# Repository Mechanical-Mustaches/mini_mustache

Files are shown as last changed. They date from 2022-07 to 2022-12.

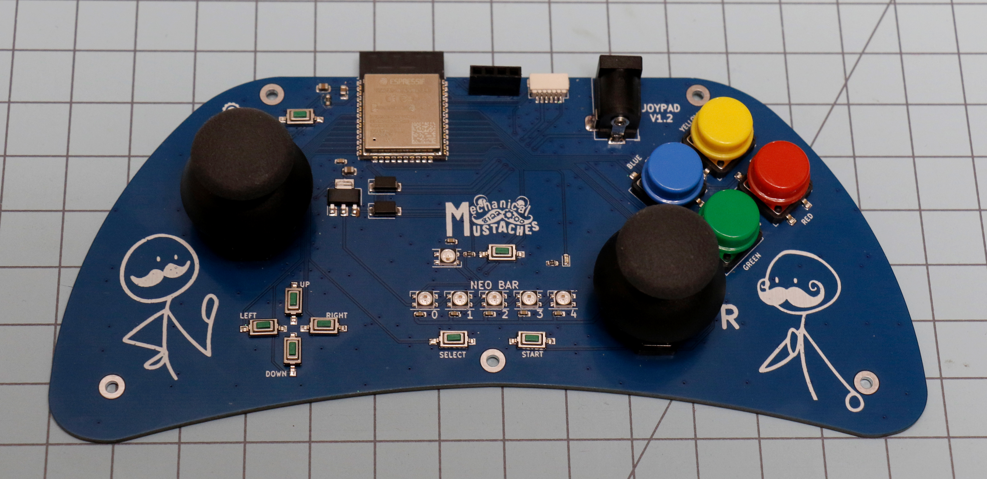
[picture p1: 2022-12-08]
press_kit/Jerry the Joypad.jpg

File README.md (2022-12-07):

Temporary home for a browser based serial terminal can be found here https://anfroholic.github.io/stache-terminal/

# Mo is live on Kickstarter!
Find more here https://www.kickstarter.com/projects/1474681136/mo-the-most-magnificent-mustached-machine 

_VZR4113

We are the Mechanical Mustaches
FIRST® Robotics Team 8122

mechanical mustaches 2022

this is Mo the mini_mustache robotic car

Mo Dance for the FIRST Time!

Mo Dances for the FIRST Time (https://www.youtube.com/watch?v=EEu2N_OLOB4)

Mo designed by our very own Olivia
mo_front
mo_back

Coming soon! Carl the Controller

carl_front
carl_back

here is a race put on by our amazing lead progammer Angie!!
Mo race_cover (https://www.youtube.com/watch?v=zQYqglGIxRU)

Still in development but some previews are:

Mo hosts webpages to edit himself
## Homepage
homepage

## Live coding REPL like code terminal
mos_repl

## Stachboard
Dashboard is autopopulated with motors, servos, agents and many other inputs and outputs that are created
stacheboard

## Mo also has an editor where you can edit your own code
editor

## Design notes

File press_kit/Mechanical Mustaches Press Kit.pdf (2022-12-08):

# Who we are

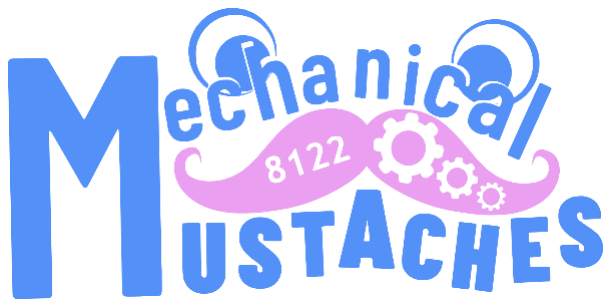
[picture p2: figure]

We are FIRST® Robotics Team 8122: The Mechanical Mustaches. We’re based out of William Howard Taft High School in Chicago, IL. FIRST is a youth-serving organization based around advancing STEM education. Every year there is a new challenge, and we build a 100+lb robot designed to complete a variety of different tasks.

We currently have about 50 team members ranging from freshmen to seniors.

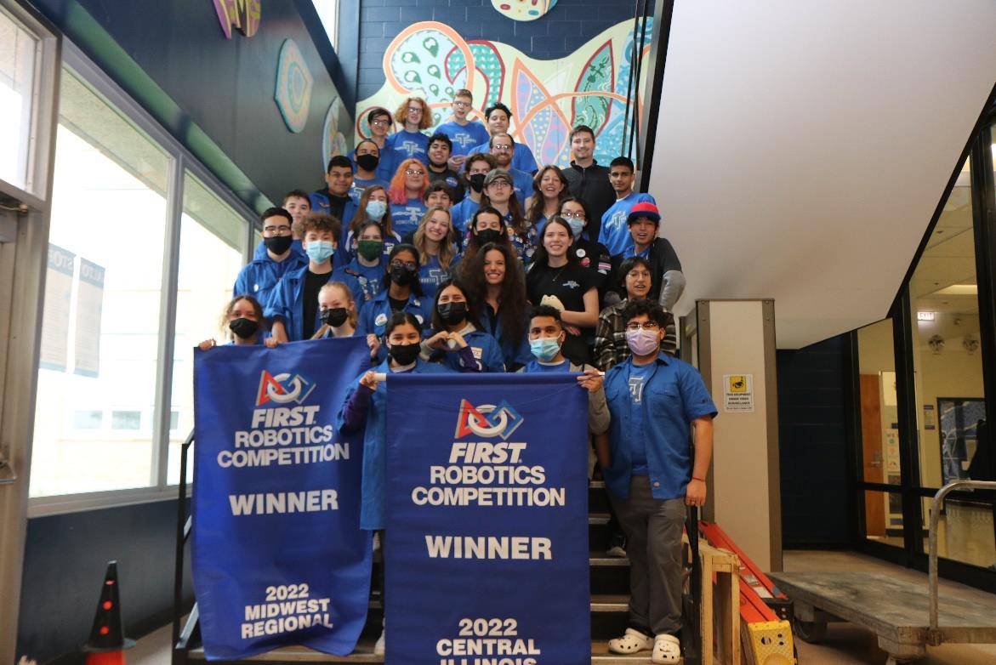
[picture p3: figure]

# Our Mission

Not everyone can grow a mustache, but everyone can grow as a mustache. We love to have fun! And the more mustache jokes the better!

We created Mo the robot to:

- To grow the use of the Python programming language in the FIRST® community
- To grow the FIRST® community by encouraging and empowering educators and coaches to start their own FIRST® Robotics teams
- To get robotics and FIRST® based curricula into the classroom

We also plan to use Mo in all these ways and the publicity generated by this campaign in a bid for our team to win the FIRST Impact Award and get our name in the FIRST Hall of Fame (https://www.firsthalloffame.org/)

# Mo the Robot

Where did Mo come from?

Mo started as a project between me, Andrew Wingate: Mentor of FIRST Robotics team 8122, The Mechanical Mustaches; and a few students to learn electrical engineering, programming and design. We didn't really have any goals other than to have fun when we started but hoped we could use this project to serve our team in the future. The large robots are expensive and access is limited. Additionally with the large robots failing is much more frowned upon. Learning should be fun and there should be no fear of getting things wrong (especially when it comes to programming)

We did have a lot of fun and the result was Mo! We shared Mo with our own students and with other teams, teachers and educators. They liked Mo too! That's when we started development on Jerry the joypad. With a controller and a robot, this really would be the same as programming the real large robots.

So we decided to try and get Mo into as many teams and schools as we could. We have talked with teams, and teachers. We have even talked with Chicago Public School's officials about getting Mo into real school curricula. Talks have been good and we’re looking forward to what’s coming.

We designed Mo to be easy to get started

- Mo serves his own webpages
- Mo has an easy-to-use autonomous mode
- Mo is programmed in python making learning easy
- Mo has a framework to help make complex systems easy
- Mo has many easy-to-use libraries already built in
- Mo already has many learning examples with more on the way

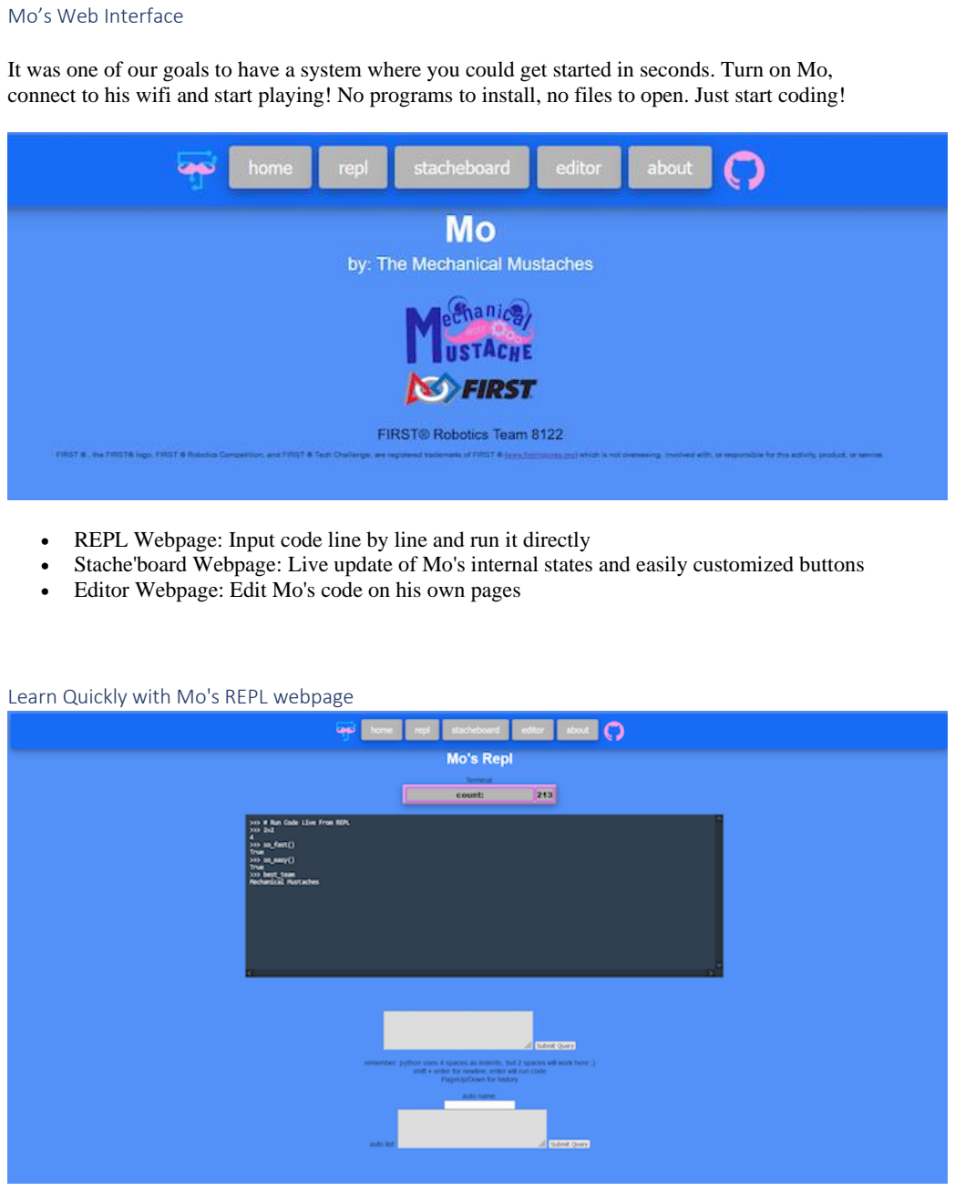
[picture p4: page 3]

Mo’s Web Interface

It was one of our goals to have a system where you could get started in seconds. Turn on Mo, connect to his wifi and start playing! No programs to install, no files to open. Just start coding!

- REPL Webpage: Input code line by line and run it directly
- Stache'board Webpage: Live update of Mo's internal states and easily customized buttons
- Editor Webpage: Edit Mo's code on his own pages

Learn Quickly with Mo's REPL webpage

- With Mo's repl you can input code directly. See immediately what your code does. If there is a mistake, Mo will tell you.
- Build confidence one line at a time.

See our repl practice on our wiki page here: (https://github.com/Mechanical-Mustaches/mini_mustache/wiki/REPL-Practice)

See live updates with Mo's Stache'board (dashboard) webpage

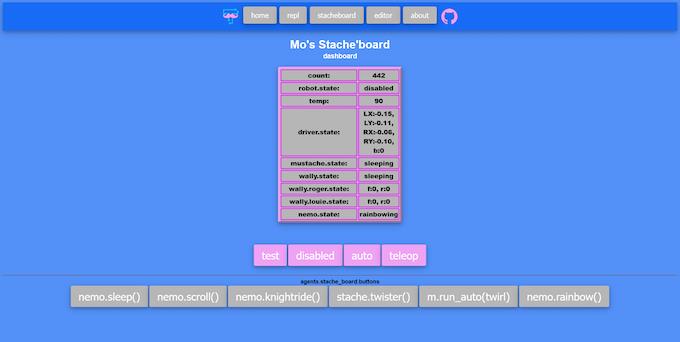
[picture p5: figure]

- With Mo's Agent based architecture important information is auto populated on Mo's Dashboard
- Easily create new buttons with custom functions
- Change Mo's states just like a real FIRST® Robotics competition robot!

Mo's Autonomous Modes

Mo comes built in with easy to use and easy to understand auto modes.

Notes from Andrew: My first career was in Tool & Die where I learned to write and use G-Code (a low level language used to drive CNC machining machines.) It was natural for me to look at lines of code and understand that the machine's would run one line of code at a time, and once that line had finished, it would move on to the next. I was amazed to find there was no comparable way to run code this way in programming languages like Python or anywhere else. So in our first season together Angie and I wrote Archie (later to be renamed mm.Auto)

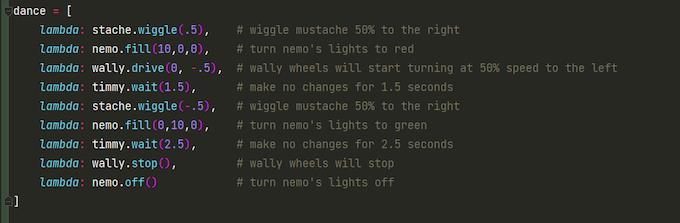
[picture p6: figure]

Mary had a little lambda

- Each line is executed one at a time in a very easy to understand fashion.
- Function calls are written the exact same way as you'd type it in code or in repl
- In 'auto' mode Auto will run all commands until it reaches a command like timmy.wait()
- Other wait like functions can be wait_for_a_button_press, or wait_until_an_encoder_reaches_position, or wait_for_counts and more
- We know what putting lambda before every function looks a little weird but it's how mm.Auto works.

You don't even need to put in all the lambdas

- In Mo's repl page is an Auto Maker that will automatically format a list and populate with all the lambdas

See more in depth explanations on Mo's wiki page (https://github.com/Mechanical-Mustaches/mini_mustache/wiki/Auto)

# Real FIRST® Robotics Robots Have Controllers

So we made Jerry the Joypad.

Jerry the Joypad is a controller you can use to remotely control Mo

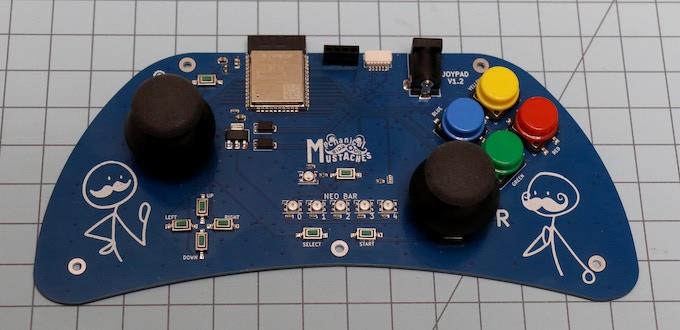
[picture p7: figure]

Jerry the Joypad Controller Board

Control Mo remotely with his friend Jerry the Joypad! Learn the interactions between a robot and a controller that is exactly the same as the interactions between controllers and FIRST® Robotics Competition Robots! Jerry and Mo talk to each other over wifi and is easy to set up

# The Most-Dashing Framework

When you learn how to program a Mo bot you already know how to program the large robots for the FIRST® Robotics competitions.

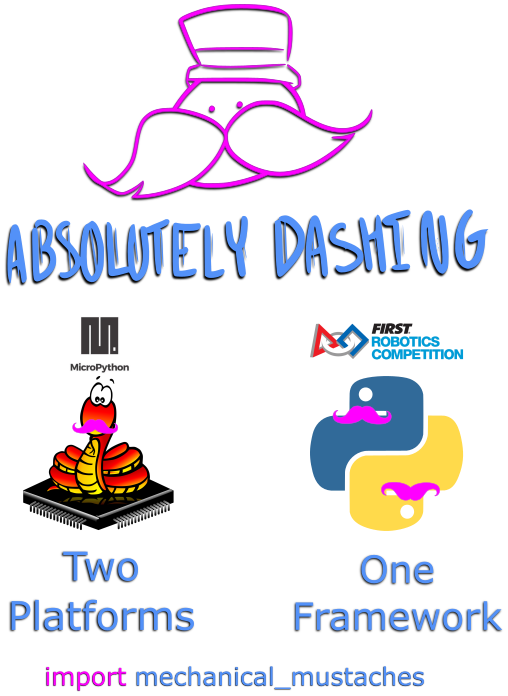
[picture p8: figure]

- Mo's framework and the Most-Dashing Framework were made at the same time
- Most code used with Mo can be directly used in FIRST®'s competition platforms

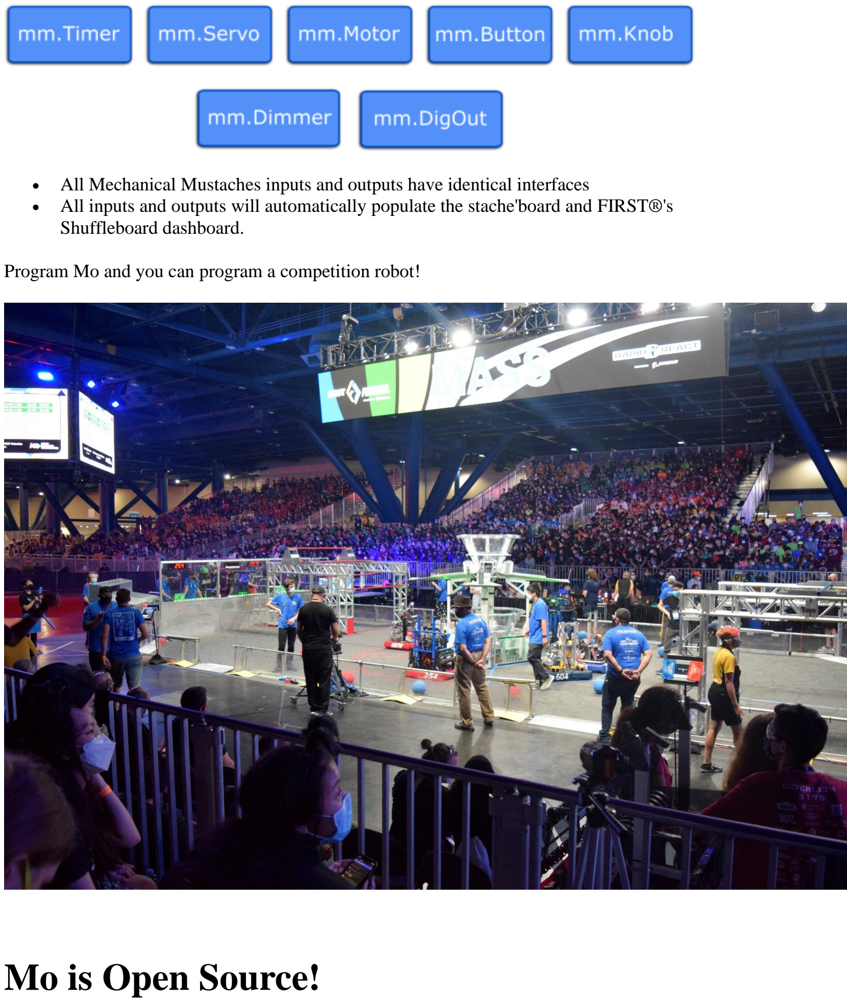
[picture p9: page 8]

- All Mechanical Mustaches inputs and outputs have identical interfaces
- All inputs and outputs will automatically populate the stache'board and FIRST®'s Shuffleboard dashboard.

Program Mo and you can program a competition robot!

# Mo is Open Source!

See our design files and code on the Mechanical Mustaches' Github pages

Mo and Jerry practice code and tutorials

- Mo's design files (https://github.com/Mechanical-Mustaches/mini_mustache/tree/main/cad-source-files/robo_car)
- Jerry's design files (https://github.com/Mechanical-Mustaches/mini_mustache/tree/main/cad-source-files/joypad)
- Mo's source code (https://github.com/Mechanical-Mustaches/mini_mustache/tree/main/code/src)
- Jerry's source code (https://github.com/Mechanical-Mustaches/mini_mustache/tree/main/code/joypad)
- Mo's expansion boards source files (https://github.com/Mechanical-Mustaches/mini_mustache/tree/main/cad-source-files/accessory-boards)

# Meet Our Build / Design Team

Meet our Lead Programmer, Angelina Bill

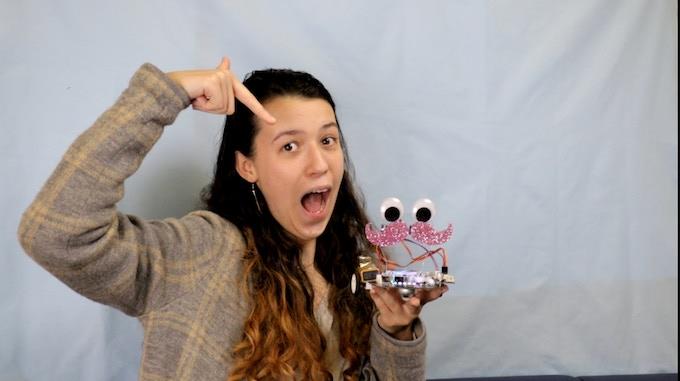
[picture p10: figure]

Meet all around Designer, Editor, Programmer and More, Yehansa Dissanayake

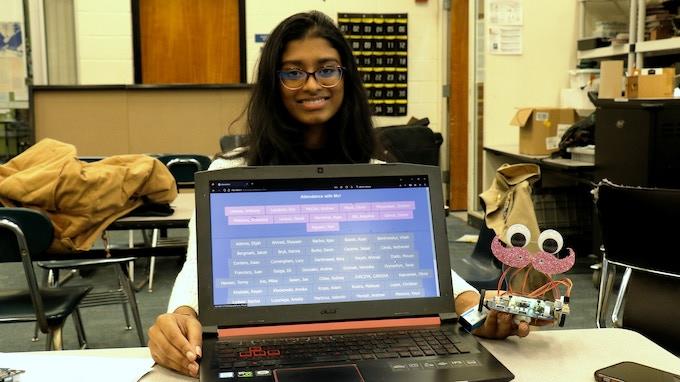
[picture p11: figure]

Yehansa used a Mo bot to take attendance for all our meetings. Mo serves an easy to use webpage where students only have to click on their name, at which point that name turns pink and moves to the top. At the same time Mo records the time and then Yehansa wrote a program that parses all the data Mo creates in an easy to parse format!

Meet our Electrical Engineer, Olivia

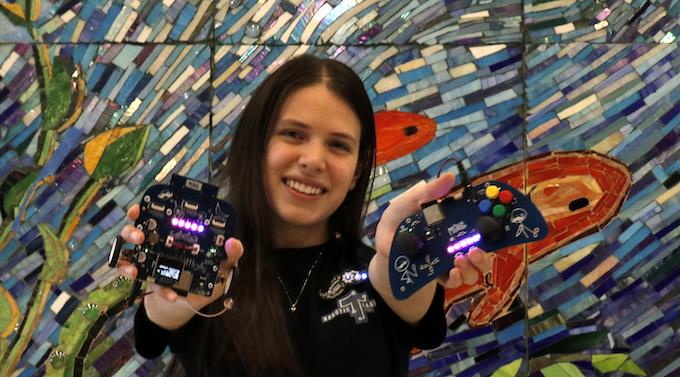
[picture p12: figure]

Olivia Kapusniak, Our Electrical Engineer

# The Story, Andrew's perspective:

Where did this project come from? The previous season, we started with a blinking cursor and had java as our language. I am a Python programmer but didn’t feel we had the time to transition the team to a new language, so we stayed with java. The next season Angie and I decided to not only move to Python (for obvious reasons) and create a framework to make development easier, faster and more fun! (not to mention a whole bunch of cool stuff.) Around the same time Olivia had stated her desire to major in college for computer engineering. We already completed a small circuit board project and I asked if she wanted to create a learning platform for our team. I was already using MicroPython in other projects so knew how we could mask the differences between the two platforms to create a smooth transition from little bots up to the big ones.

A few months later we knew a little about what we created and decided to create this campaign as a part of our bid for the FIRST® Robotics Impact Award. (https://www.firstinspires.org/resource-library/frc/first-impact-award-resources) Having been a part of a few teams now, I can say without a doubt that programming is the greatest hurdle both new and established teams face every year. The FIRST® community is wonderful. On a couple occasions we had other team’s programmers going around and helping teams polish their code on competition days. I wondered how many teams just don’t get started because the teacher or coach just didn’t think they had what it took to make a complete robot. If there was a way to cheaply prove that they were capable of creating a working program how many more teams could there be? At this point we had a few robots completed and were beginning to transition into the classroom environment. It was a goal that these robots would be able to be programmed on the hardware offered in the classrooms and more specifically CPS. (https://www.cps.edu/) In this case it was chromebooks. Not only could you not install programs on these devices, but you couldn’t even stick a thumb drive into them. (This is not because they are not capable of this, but more because of decisions made by CPS as an organization.)

So Mo got browser support. Luckily the microcontroller we were already using supported wifi and we began web development. This is where I finally started to believe that we actually had something. These little Mo bots start were a really good tool. (see campaign page for more) Not only was I able to teach a few kids to code, such as my nieces and nephews, but Angie herself was able to teach a classroom full of kids to program. Not only to program but create fun games like races and more. If a high school student could teach a bunch of kids, I have real hopes that we could make an impact and move a majority of FIRST® Robotics Teams over to a language more used in industry like Python than a language being used less and less like java. It’s my belief that it’s a necessity that our next generations have the ability to leverage robotic technologies. They must be orders of magnitude more productive than generations of the past. No longer will having a job of taking a doughnut from a conveyor and putting it in a box be a viable choice. We not only have to do all the work we’ve been doing, we also need to do all the work that we wish to have, so everyone can raise their standard of living. On top of all that we need to undo much of the poor work that has been done in the past, so we may restore and create a better world. I believe it’s in this generation to complete these tasks and more!

I would like to close with as much praise as I can muster to the three wonderful ladies that took charge of this project. Angie, Yehansa and Olivia have done a fantastic job and I couldn’t be prouder, not only for the work completed, but for their tenacity and willingness to stand up. I don’t really like phrases like “Women in STEM,” but I do agree with the sentiment. What I really want to see is more women in positions of power. I am saying these words more for the women I’ve worked with, than the general population. I have heard from women who have felt well mentored, but overlooked when it finally came time to pass the reigns. As a mentor myself, that puts me in a difficult situation. I try at every possible occasion to relieve myself from the decision making process, so they may flex those muscles and understand how it feels. Then use those muscles when it matters and have the confidence to take charge.

Contacts

Webpage: https://taftrobotics8122.wixsite.com/mechanical-mustaches

Github: https://github.com/Mechanical-Mustaches

Youtube: https://www.youtube.com/channel/UCmcKjrg92jrgkpf-8tHtKkQ

Twitter: https://twitter.com/RoboticsTaft

Instagram: https://www.instagram.com/8122_taftrobotics/

Andrew Wingate

Mentor: Mechanical Mustaches

President: Evezor Inc.

andrew@evezor.com

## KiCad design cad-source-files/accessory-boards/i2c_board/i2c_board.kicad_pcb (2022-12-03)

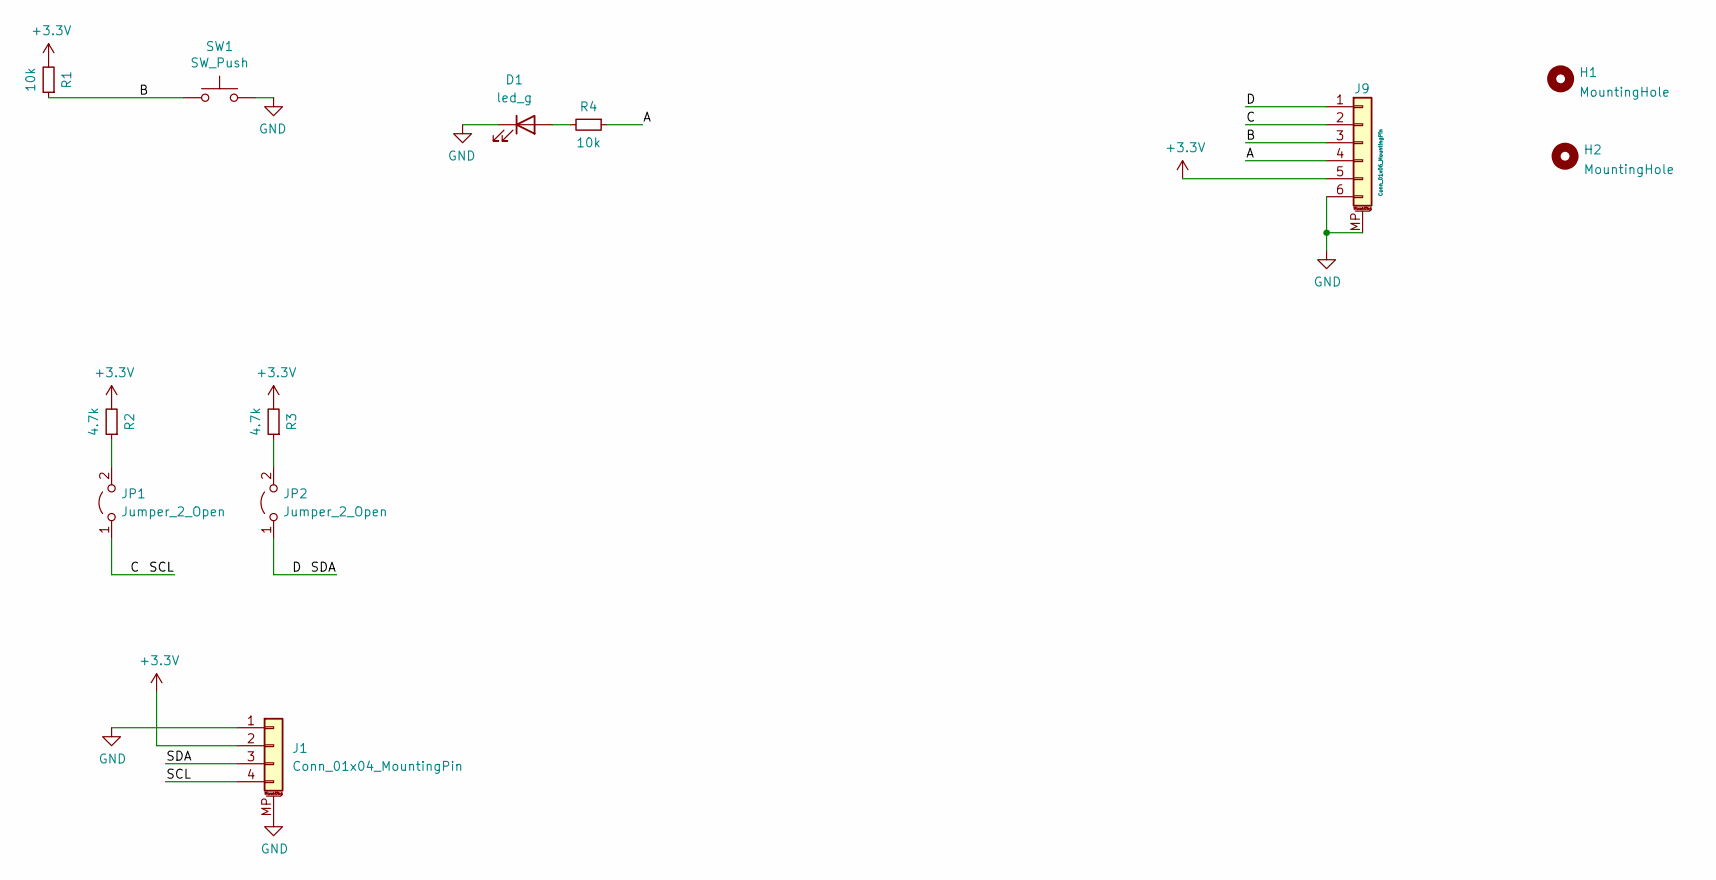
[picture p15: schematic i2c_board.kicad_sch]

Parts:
D1: led_g; LED_0603_1608Metric
H1, H2: MountingHole; MountingHole_3.2mm_M3_ISO14580
J1: Conn_01x04_MountingPin; JST_SH_SM04B-SRSS-TB_1x04-1MP_P1.00mm_Horizontal
J9: Conn_01x06_MountingPin; TE_84952-6_1x06-1MP_P1.0mm_Horizontal
JP1, JP2: Jumper_2_Open; SolderJumper-2_P1.3mm_Bridged_RoundedPad1.0x1.5mm
R1, R4: 10k; R_0603_1608Metric
R2, R3: 4.7k; R_0603_1608Metric
SW1: SW_Push; SWITCH_2x3_SMD_TACTILE_GREEN

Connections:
+3V3: J1.2, J9.5, R1.2, R2.2, R3.2
/A: J9.4, R4.1
/B: J9.3, R1.1, SW1.1
/C: J1.4, J9.2, JP1.1 (A)
/D: J1.3, J9.1, JP2.1 (A)
GND: D1.1 (K), J1.1, J1.MP (MountPin), J9.6, J9.MP (MountPin), SW1.2
unnamed: D1.2 (A), R4.2
unnamed: JP1.2 (B), R2.1
unnamed: JP2.2 (B), R3.1

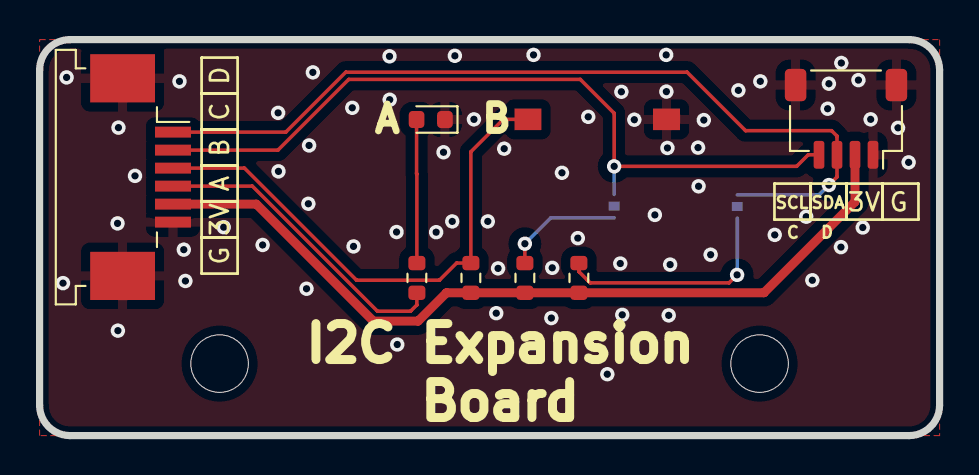
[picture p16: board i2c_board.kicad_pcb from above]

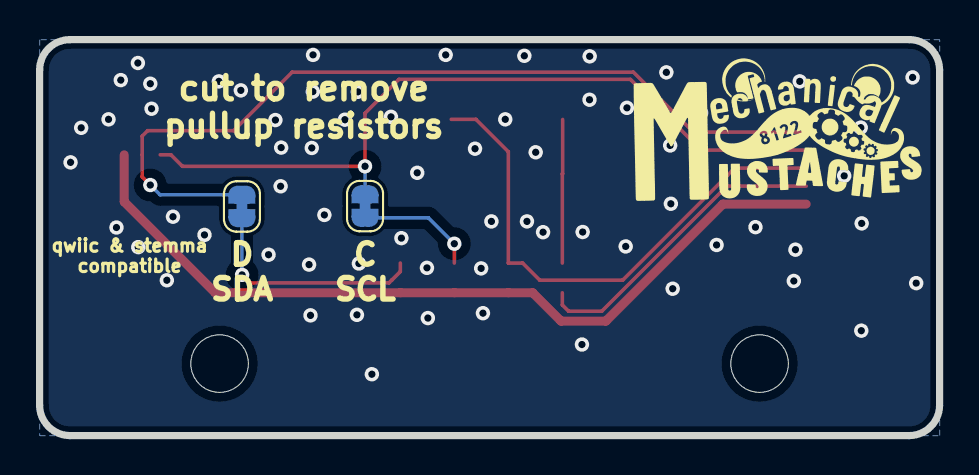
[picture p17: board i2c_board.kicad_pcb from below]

Board: 2 copper layers, 50.0 x 22.0 mm, 12 parts (2 on the bottom side), 9 nets.

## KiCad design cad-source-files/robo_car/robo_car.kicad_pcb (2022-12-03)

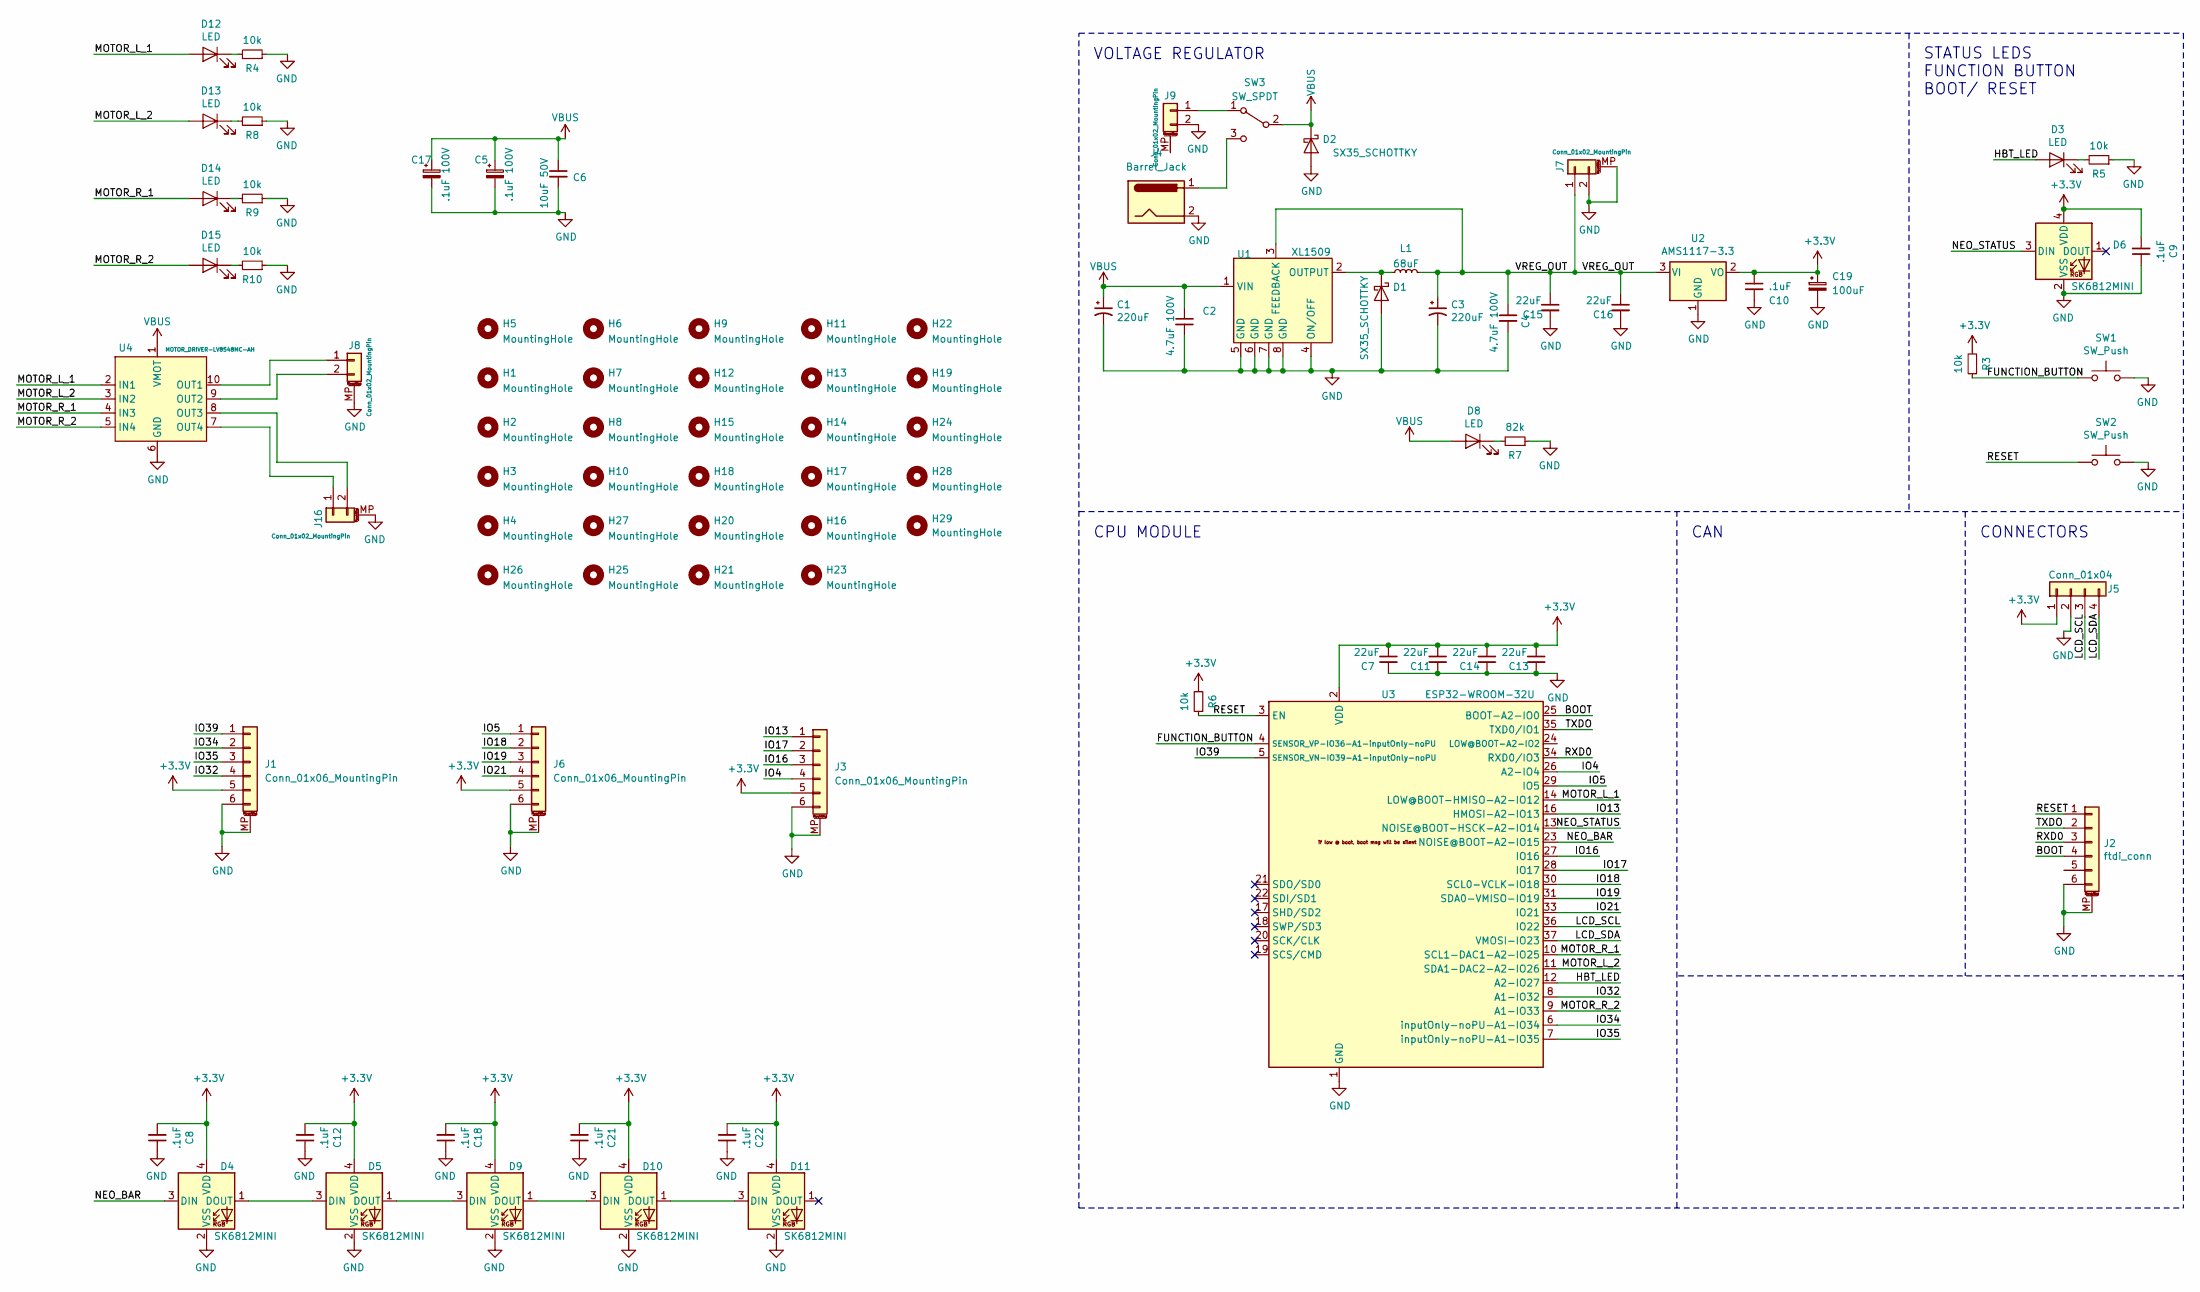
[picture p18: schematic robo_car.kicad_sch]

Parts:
C1, C3: 220uF; CP_Elec_10x10.5
C2, C4: 4.7uF 100V; C_0805_2012Metric
C5, C17: .1uF 100V; C_0805_2012Metric
C6: 10uF 50V; C_1206_3216Metric
C7, C11, C13, C14, C15, C16: 22uF; C_0805_2012Metric
C8, C9, C10, C12, C18, C21, C22: .1uF; C_0603_1608Metric
C19: 100uF; CP_EIA-3528-21_Kemet-B
D1, D2: SX35_SCHOTTKY; D_SMA
D3, D8, D12, D13, D14, D15: LED; LED_0603_1608Metric
D4, D5, D6, D9, D10, D11: SK6812MINI; LED_SK6812MINI_PLCC4_3.5x3.5mm_P1.75mm
H1, H2, H3, H4, H5, H6, H7, H8, H9, H10, H11, H12, H13, H14, H15, H16, H17, H18, H19, H20, H25, H26, H27, H28, H29: MountingHole; MountingHole_3.2mm_M3_ISO14580
H21, H22, H23, H24: MountingHole; MountingHole_2.7mm_M2.5_ISO14580
J1, J3, J6: Conn_01x06_MountingPin; TE_84952-6_1x06-1MP_P1.0mm_Horizontal
J2: ftdi_conn; JST_SH_SM06B-SRSS-TB_1x06-1MP_P1.00mm_Horizontal
J4: Barrel_Jack; BarrelJack_Horizontal
J5: Conn_01x04; PinSocket_1x04_P2.54mm_Vertical
J7: Conn_01x02_MountingPin; JST_PH_B2B-PH-K_1x02_P2.00mm_Vertical
J8, J16: Conn_01x02_MountingPin; JST_PH_S2B-PH-K_1x02_P2.00mm_Horizontal
J9: Conn_01x02_MountingPin; JST_XH_B2B-XH-AM_1x02_P2.50mm_Vertical
L1: 68uF; INDUCTOR-68uH
R3, R4, R5, R6, R8, R9, R10: 10k; R_0603_1608Metric
R7: 82k; R_0603_1608Metric
SW1, SW2: SW_Push; SWITCH_2x3_SMD_TACTILE_GREEN
SW3: SW_SPDT; SW_SLIDE_SS-12D10L9
U1: XL1509; SOIC-8_3.9x4.9mm_P1.27mm
U2: AMS1117-3.3; SOT-223-3_TabPin2
U3: ESP32-WROOM-32U; ESP32-WROOM-32U_evezor
U4: MOTOR_DRIVER-LV8548MC-AH; SOIC-10_LV8548MC-AH_evezor

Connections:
+3V3: C7.1, C8.2, C9.2, C10.1, C11.1, C12.2, C13.1, C14.1, C18.2, C19.1, C21.2, C22.2, D4.4 (VDD), D5.4 (VDD), D6.4 (VDD), D9.4 (VDD), D10.4 (VDD), D11.4 (VDD), J1.5, J3.5, J5.1, J6.5, R3.2, R6.2, U2.2 (VO), U3.2 (VDD); also elsewhere on the board
/BOOT: J2.4, U3.25 (BOOT-A2-IO0)
/FUNCTION_BUTTON: R3.1, SW1.1, U3.4 (SENSOR_VP-IO36-A1-inputOnly-noPU)
/HBT_LED: D3.2 (A), U3.12 (A2-IO27)
/IO4: J3.4, U3.26 (A2-IO4)
/IO5: J6.1, U3.29 (IO5)
/IO13: J3.1, U3.16 (HMOSI-A2-IO13)
/IO16: J3.3, U3.27 (IO16)
/IO17: J3.2, U3.28 (IO17)
/IO18: J6.2, U3.30 (SCL0-VCLK-IO18)
/IO19: J6.3, U3.31 (SDA0-VMISO-IO19)
/IO21: J6.4, U3.33 (IO21)
/IO32: J1.4, U3.8 (A1-IO32)
/IO34: J1.2, U3.6 (inputOnly-noPU-A1-IO34)
/IO35: J1.3, U3.7 (inputOnly-noPU-A1-IO35)
/IO39: J1.1, U3.5 (SENSOR_VN-IO39-A1-inputOnly-noPU)
/LCD_SCL: J5.3, U3.36 (IO22)
/LCD_SDA: J5.4, U3.37 (VMOSI-IO23)
/MOTOR_L_1: D12.2 (A), U3.14 (LOW@BOOT-HMISO-A2-IO12), U4.2 (IN1)
/MOTOR_L_2: D13.2 (A), U3.11 (SDA1-DAC2-A2-IO26), U4.3 (IN2)
/MOTOR_R_1: D14.2 (A), U3.10 (SCL1-DAC1-A2-IO25), U4.4 (IN3)
/MOTOR_R_2: D15.2 (A), U3.9 (A1-IO33), U4.5 (IN4)
/NEO_BAR: D4.3 (DIN), U3.23 (NOISE@BOOT-A2-IO15)
/NEO_STATUS: D6.3 (DIN), U3.13 (NOISE@BOOT-HSCK-A2-IO14)
/RESET: J2.1, R6.1, SW2.1, U3.3 (EN)
/RXD0: J2.3, U3.34 (RXD0/IO3)
/TXDO: J2.2, U3.35 (TXD0/IO1)
/VREG_OUT: C3.1, C4.1, C15.1, C16.1, J7.1, L1.1, U1.3 (FEEDBACK), U2.3 (VI)
GND: C1.2, C2.2, C3.2, C4.2, C5.2, C6.2, C7.2, C8.1, C9.1, C10.2, C11.2, C12.1, C13.2, C14.2, C15.2, C16.2, C17.2, C18.1, C19.2, C21.1, C22.1, D1.2 (A), D2.2 (A), D4.2 (VSS), D5.2 (VSS), D6.2 (VSS), D9.2 (VSS), D10.2 (VSS), D11.2 (VSS), J1.6, J1.MP (MountPin), J2.6, J2.MP (MountPin), J3.6, J3.MP (MountPin), J4.2, J5.2, J6.6, J6.MP (MountPin), J7.2, J7.MP (MountPin), J8.MP (MountPin), J9.2, J16.MP (MountPin), R4.1, R5.1, R7.1, R8.1, R9.1, R10.1, SW1.2, SW2.2, U1.4 (ON/OFF), U1.5 (GND), U1.6 (GND), U1.7 (GND), U1.8 (GND), U2.1 (GND), U3.1 (GND), U3.15 (GND), U3.38 (GND), U3.39 (GND), U4.6 (GND); also elsewhere on the board
unnamed: D1.1 (K), L1.2, U1.2 (OUTPUT)
unnamed: D3.1 (K), R5.2
unnamed: D4.1 (DOUT), D5.3 (DIN)
unnamed: D5.1 (DOUT), D9.3 (DIN)
unnamed: D8.1 (K), R7.2
unnamed: D10.1 (DOUT), D11.3 (DIN)
unnamed: D9.1 (DOUT), D10.3 (DIN)
unnamed: D12.1 (K), R4.2
unnamed: D13.1 (K), R8.2
unnamed: D14.1 (K), R9.2
unnamed: D15.1 (K), R10.2
unnamed: J4.1, SW3.3 (C)
unnamed: J8.1, U4.10 (OUT1)
unnamed: J8.2, U4.9 (OUT2)
unnamed: J9.1, SW3.1 (A)
unnamed: J16.1, U4.7 (OUT4)
unnamed: J16.2, U4.8 (OUT3)
VBUS: C1.1, C2.1, C5.1, C6.1, C17.1, D2.1 (K), D8.2 (A), SW3.2 (B), U1.1 (VIN), U4.1 (VMOT)

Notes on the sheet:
VOLTAGE REGULATOR
CPU MODULE
CAN
STATUS LEDS FUNCTION BUTTON BOOT/ RESET
CONNECTORS

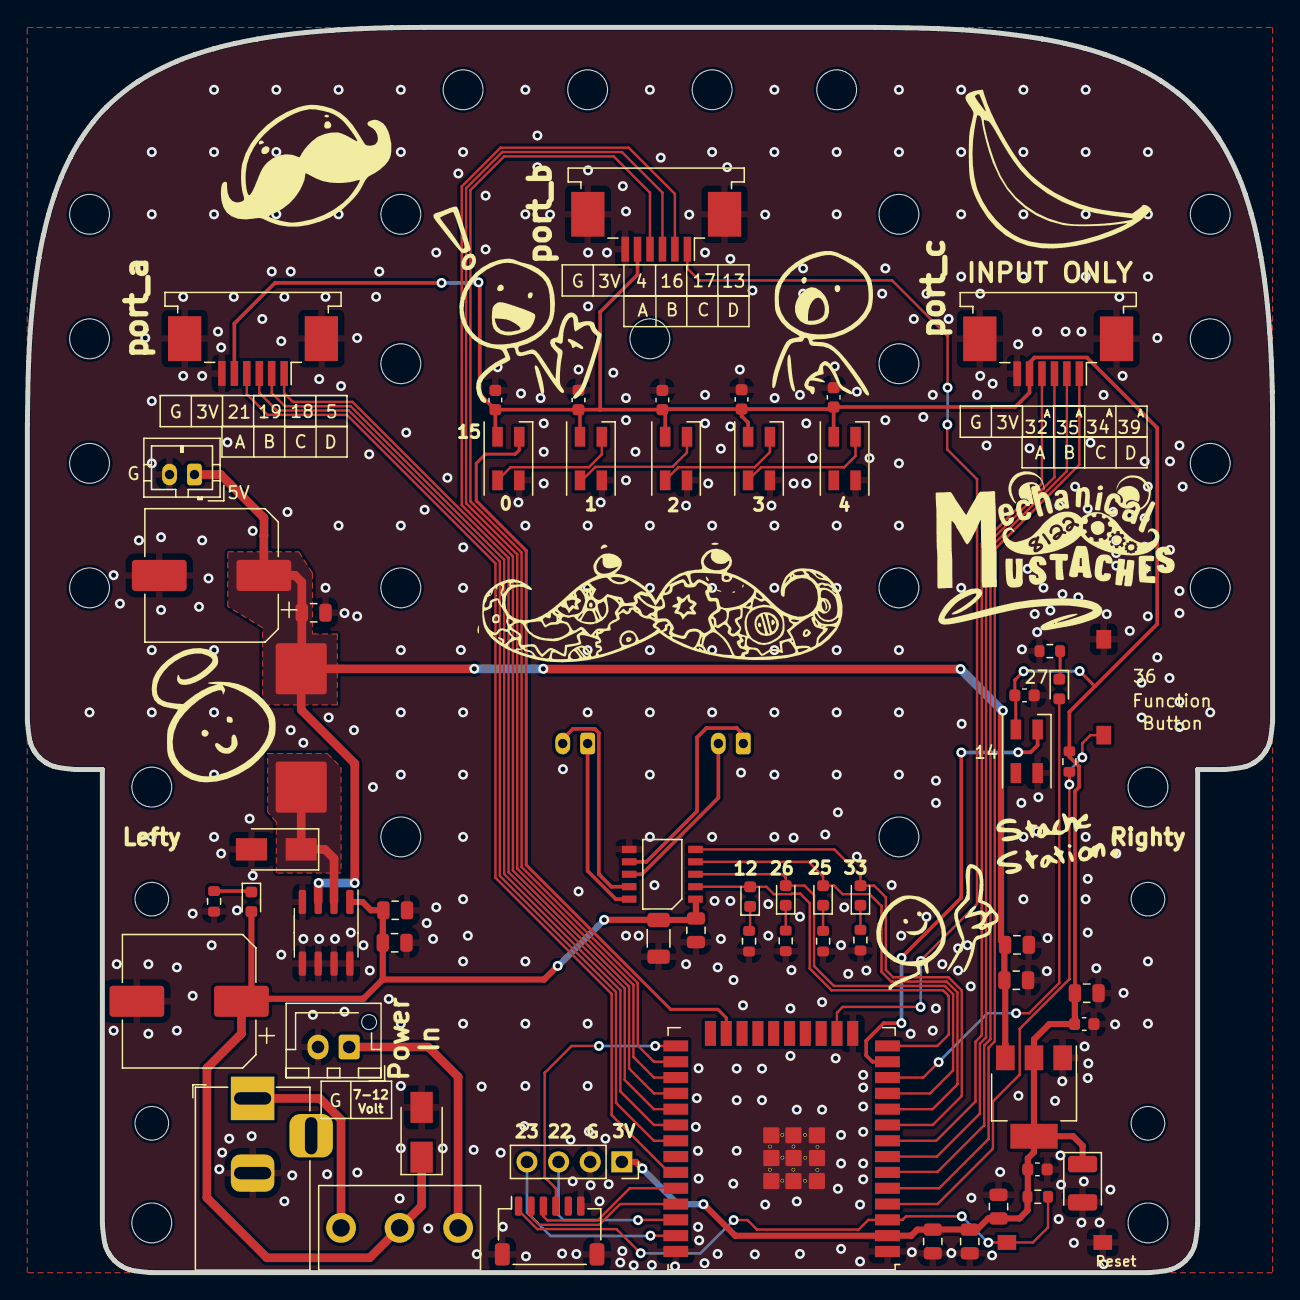
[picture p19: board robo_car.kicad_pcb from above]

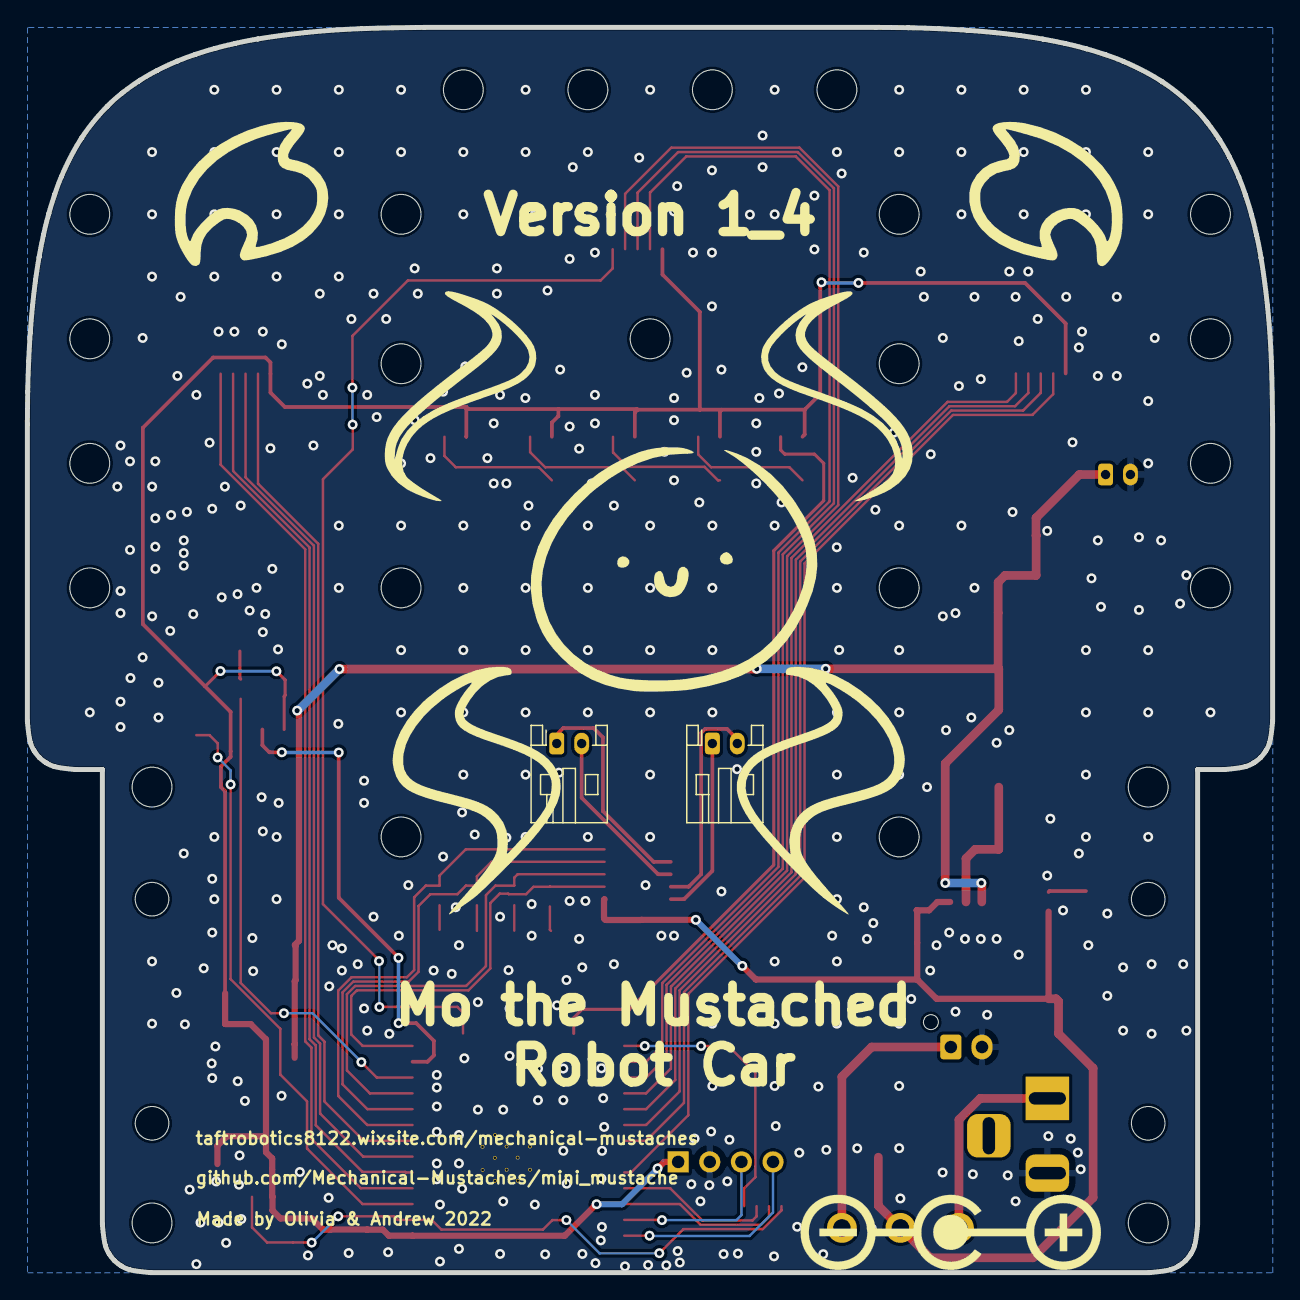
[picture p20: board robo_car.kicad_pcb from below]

Board: 2 copper layers, 100.0 x 100.0 mm, 91 parts (2 on the bottom side), 47 nets.

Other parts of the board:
C14#2: .1uF; C_0603_1608Metric

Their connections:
+3V3: C14#2.1; also elsewhere on the board
GND: C14#2.2; also elsewhere on the board

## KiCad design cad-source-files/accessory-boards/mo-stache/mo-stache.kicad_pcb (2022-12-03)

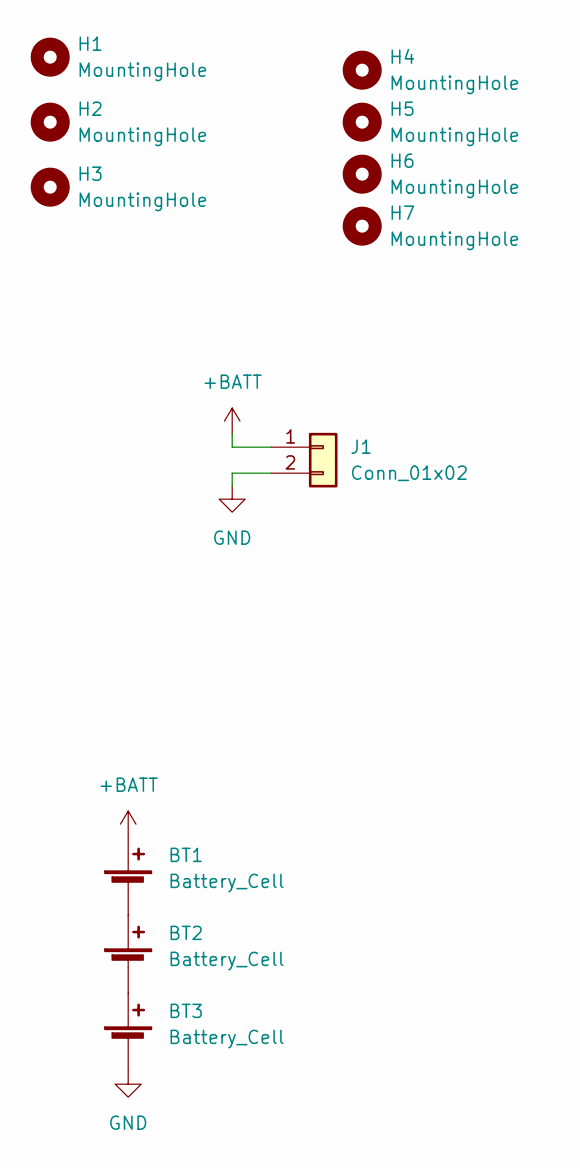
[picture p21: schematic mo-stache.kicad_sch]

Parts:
BT1, BT2, BT3: Battery_Cell; 16350_holder
H1, H2, H3: MountingHole; MountingHole_4.95mm_3_16in
H4, H5, H6, H7: MountingHole; MountingHole_2.7mm_M2.5_ISO7380
J1: Conn_01x02; JST_XH_B2B-XH-AM_1x02_P2.50mm_Vertical

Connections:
+BATT: BT1.1 (+), J1.1
GND: BT3.2 (-), J1.2
unnamed: BT1.2 (-), BT2.1 (+)
unnamed: BT2.2 (-), BT3.1 (+)

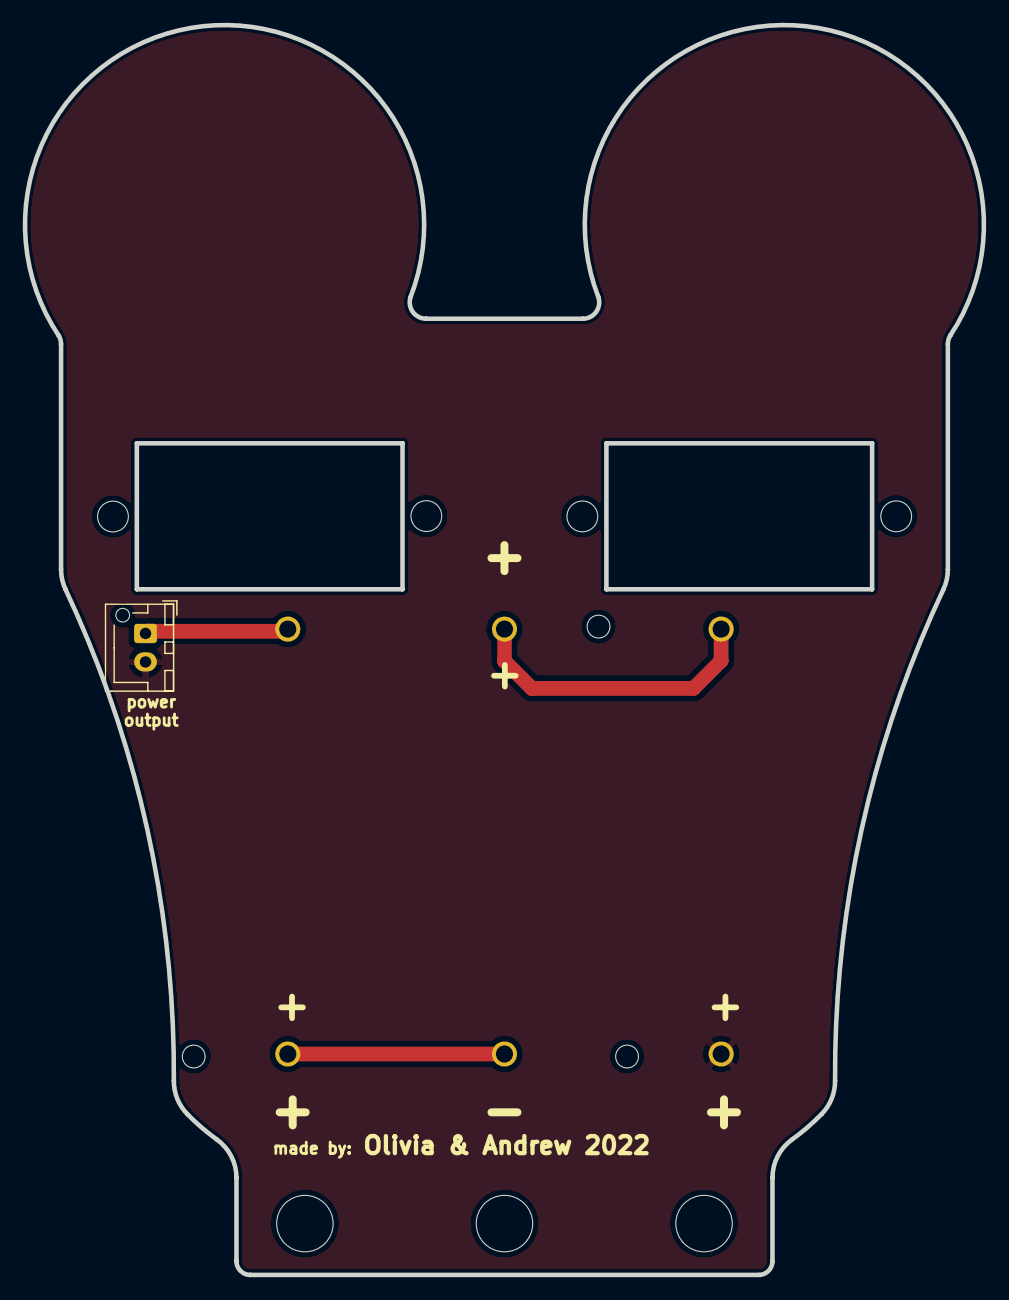
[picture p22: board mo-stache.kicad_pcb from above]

Board: 2 copper layers, 84.1 x 109.6 mm, 11 parts (0 on the bottom side), 4 nets.

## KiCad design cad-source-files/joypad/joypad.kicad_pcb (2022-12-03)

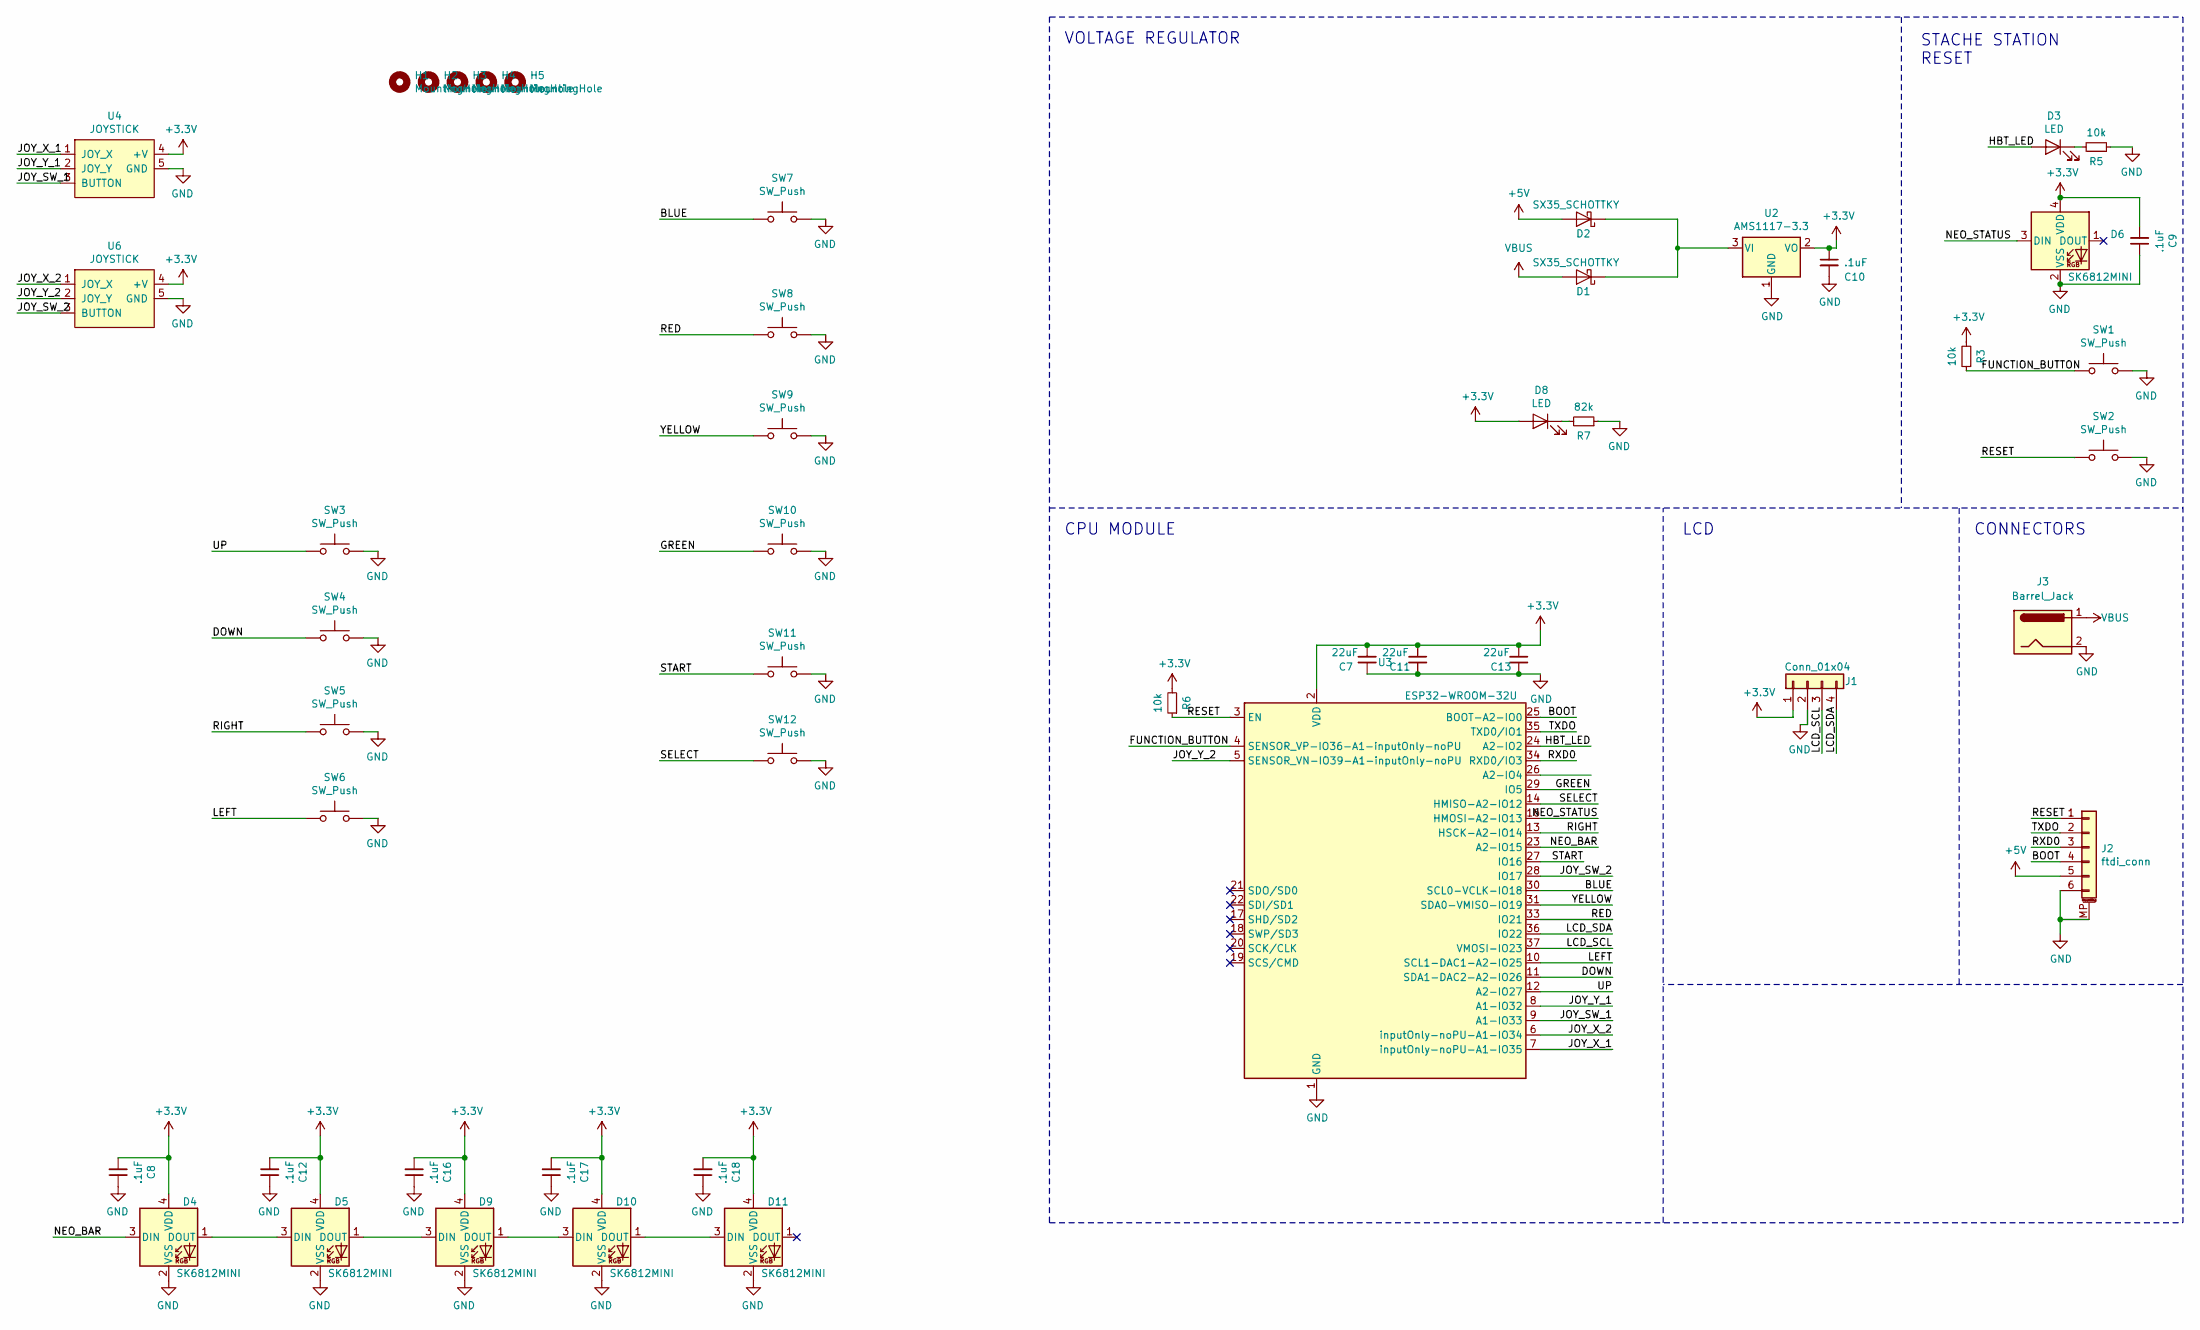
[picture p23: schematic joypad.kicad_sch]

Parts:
C7, C11, C13: 22uF; C_0805_2012Metric
C8, C9, C10, C12, C16, C17, C18: .1uF; C_0603_1608Metric
D1, D2: SX35_SCHOTTKY; D_SMA
D3, D8: LED; LED_0603_1608Metric
D4, D5, D6, D9, D10, D11: SK6812MINI; LED_SK6812MINI_PLCC4_3.5x3.5mm_P1.75mm
H1, H2, H3, H4, H5: MountingHole; MountingHole_2.5mm_Pad
J1: Conn_01x04; PinSocket_1x04_P2.54mm_Vertical
J2: ftdi_conn; JST_SH_SM06B-SRSS-TB_1x06-1MP_P1.00mm_Horizontal
J3: Barrel_Jack; BarrelJack_Horizontal
R3, R5, R6: 10k; R_0603_1608Metric
R7: 82k; R_0603_1608Metric
SW1, SW2, SW3, SW4, SW5, SW6, SW11, SW12: SW_Push; SWITCH_2x3_SMD_TACTILE_GREEN
SW7, SW8, SW9, SW10: SW_Push; 12mm_pushbutton
U2: AMS1117-3.3; SOT-223-3_TabPin2
U3: ESP32-WROOM-32U; ESP32-WROOM-32U_evezor
U4, U6: JOYSTICK

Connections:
+3V3: C7.1, C8.2, C9.2, C10.1, C11.1, C12.2, C13.1, C16.2, C17.2, C18.2, D4.4 (VDD), D5.4 (VDD), D6.4 (VDD), D8.2 (A), D9.4 (VDD), D10.4 (VDD), D11.4 (VDD), J1.1, R3.2, R6.2, U2.2 (VO), U3.2 (VDD), U4.4 (+V), U6.4 (+V)
+5V: D2.2 (A), J2.5
/BLUE: SW7.1, U3.30 (SCL0-VCLK-IO18)
/BOOT: J2.4, U3.25 (BOOT-A2-IO0)
/DOWN: SW4.1, U3.11 (SDA1-DAC2-A2-IO26)
/FUNCTION_BUTTON: R3.1, SW1.1, U3.4 (SENSOR_VP-IO36-A1-inputOnly-noPU)
/GREEN: SW10.1, U3.29 (IO5)
/HBT_LED: D3.2 (A), U3.24 (A2-IO2)
/JOY_SW_1: U3.9 (A1-IO33), U4.3 (BUTTON)
/JOY_SW_2: U3.28 (IO17), U6.3 (BUTTON)
/JOY_X_1: U3.7 (inputOnly-noPU-A1-IO35), U4.1 (JOY_X)
/JOY_X_2: U3.6 (inputOnly-noPU-A1-IO34), U6.1 (JOY_X)
/JOY_Y_1: U3.8 (A1-IO32), U4.2 (JOY_Y)
/JOY_Y_2: U3.5 (SENSOR_VN-IO39-A1-inputOnly-noPU), U6.2 (JOY_Y)
/LCD_SCL: J1.3, U3.37 (VMOSI-IO23)
/LCD_SDA: J1.4, U3.36 (IO22)
/LEFT: SW6.1, U3.10 (SCL1-DAC1-A2-IO25)
/NEO_BAR: D4.3 (DIN), U3.23 (A2-IO15)
/NEO_STATUS: D6.3 (DIN), U3.16 (HMOSI-A2-IO13)
/RED: SW8.1, U3.33 (IO21)
/RESET: J2.1, R6.1, SW2.1, U3.3 (EN)
/RIGHT: SW5.1, U3.13 (HSCK-A2-IO14)
/RXD0: J2.3, U3.34 (RXD0/IO3)
/SELECT: SW12.1, U3.14 (HMISO-A2-IO12)
/START: SW11.1, U3.27 (IO16)
/TXDO: J2.2, U3.35 (TXD0/IO1)
/UP: SW3.1, U3.12 (A2-IO27)
/YELLOW: SW9.1, U3.31 (SDA0-VMISO-IO19)
GND: C7.2, C8.1, C9.1, C10.2, C11.2, C12.1, C13.2, C16.1, C17.1, C18.1, D4.2 (VSS), D5.2 (VSS), D6.2 (VSS), D9.2 (VSS), D10.2 (VSS), D11.2 (VSS), J1.2, J2.6, J2.MP (MountPin), J3.2, R5.1, R7.1, SW1.2, SW2.2, SW3.2, SW4.2, SW5.2, SW6.2, SW7.2, SW8.2, SW9.2, SW10.2, SW11.2, SW12.2, U2.1 (GND), U3.1 (GND), U3.15 (GND), U3.38 (GND), U3.39 (GND), U4.5 (GND), U6.5 (GND)
unnamed: D1.1 (K), D2.1 (K), U2.3 (VI)
unnamed: D3.1 (K), R5.2
unnamed: D4.1 (DOUT), D5.3 (DIN)
unnamed: D5.1 (DOUT), D9.3 (DIN)
unnamed: D8.1 (K), R7.2
unnamed: D10.1 (DOUT), D11.3 (DIN)
unnamed: D9.1 (DOUT), D10.3 (DIN)
VBUS: D1.2 (A), J3.1

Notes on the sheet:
VOLTAGE REGULATOR
CPU MODULE
LCD
STACHE STATION RESET
CONNECTORS

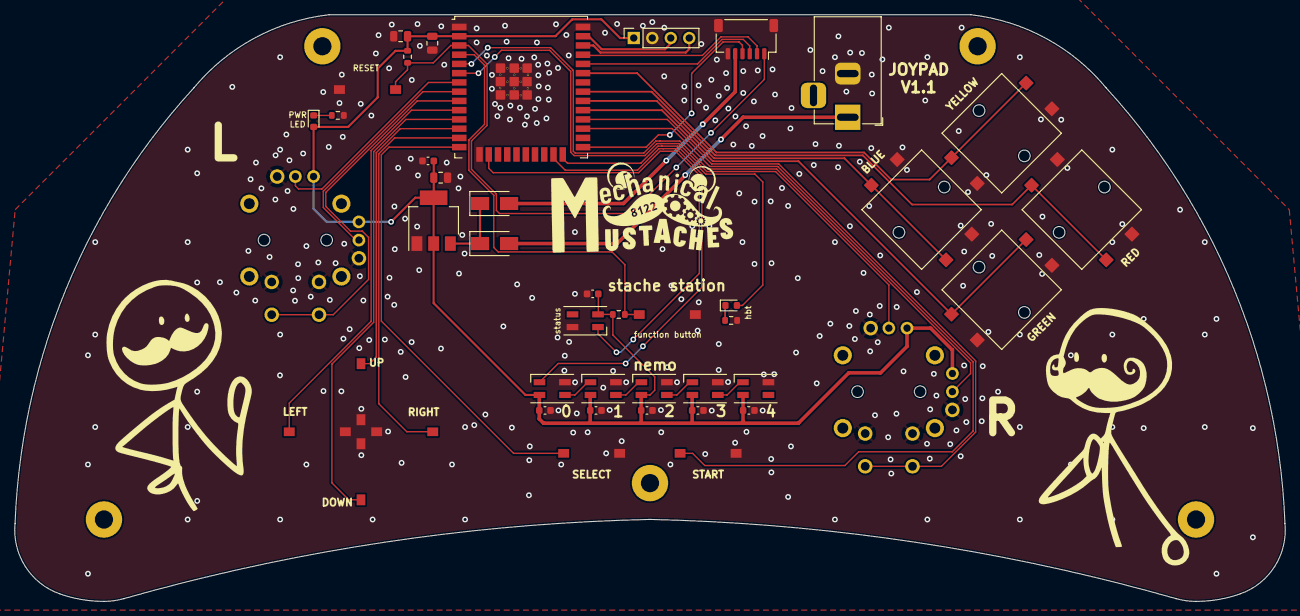
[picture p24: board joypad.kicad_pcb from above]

Board: 2 copper layers, 174.5 x 80.6 mm, 48 parts (0 on the bottom side), 37 nets.

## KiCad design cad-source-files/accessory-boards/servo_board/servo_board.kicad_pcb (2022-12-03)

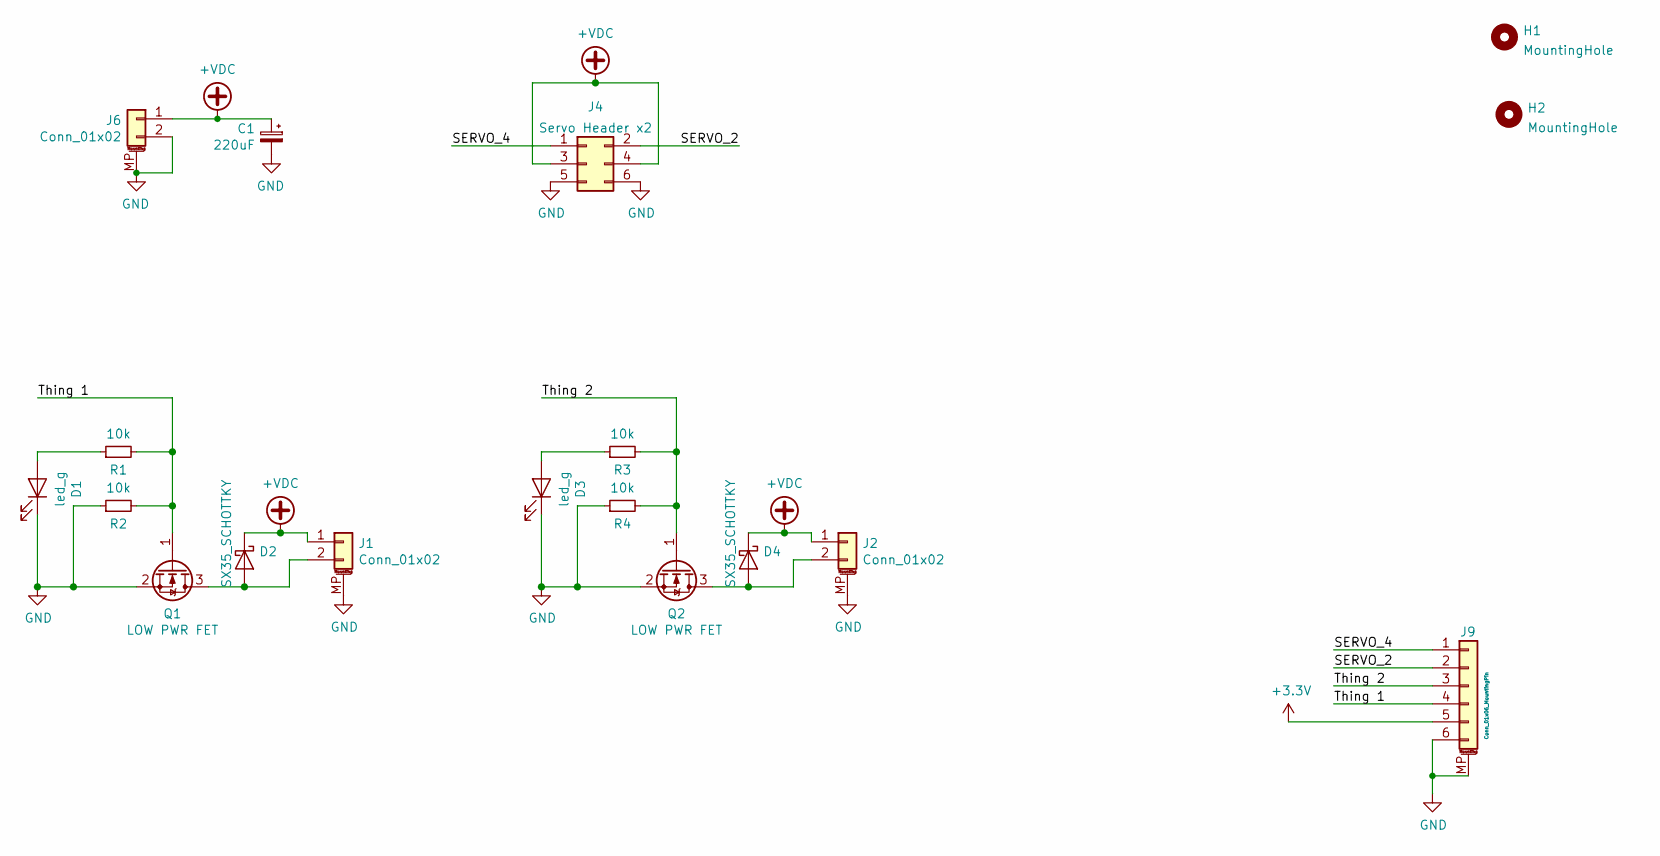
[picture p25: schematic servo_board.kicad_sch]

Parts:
C1: 220uF; CP_Elec_8x6.5
D1, D3: led_g; LED_0603_1608Metric
D2, D4: SX35_SCHOTTKY; D_SMA
H1, H2: MountingHole; MountingHole_3.2mm_M3_ISO14580
J1, J2: Conn_01x02; JST_XH_2_VERTICAL
J4: Servo Header x2; PinHeader_2x03_P2.54mm_Vertical_SMD
J6: Conn_01x02; JST_PH_B2B-PH-SM4-TB_1x02-1MP_P2.00mm_Vertical
J9: Conn_01x06_MountingPin; TE_84952-6_1x06-1MP_P1.0mm_Horizontal
Q1, Q2: LOW PWR FET; SOT-23
R1, R2, R3, R4: 10k; R_0603_1608Metric

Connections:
+3V3: J9.5
+VDC: C1.1, D2.1 (K), D4.1 (K), J1.1, J2.1, J4.3, J4.4, J6.1
/SERVO_2: J4.2, J9.2
/SERVO_4: J4.1, J9.1
/Thing 1: J9.4, Q1.1 (G), R1.2, R2.2
/Thing 2: J9.3, Q2.1 (G), R3.2, R4.2
GND: C1.2, D1.1 (K), D3.1 (K), J1.MP (MountPin), J2.MP (MountPin), J4.5, J4.6, J6.2, J6.MP (MountPin), J9.6, J9.MP (MountPin), Q1.2 (S), Q2.2 (S), R2.1, R4.1
unnamed: D1.2 (A), R1.1
unnamed: D2.2 (A), J1.2, Q1.3 (D)
unnamed: D3.2 (A), R3.1
unnamed: D4.2 (A), J2.2, Q2.3 (D)

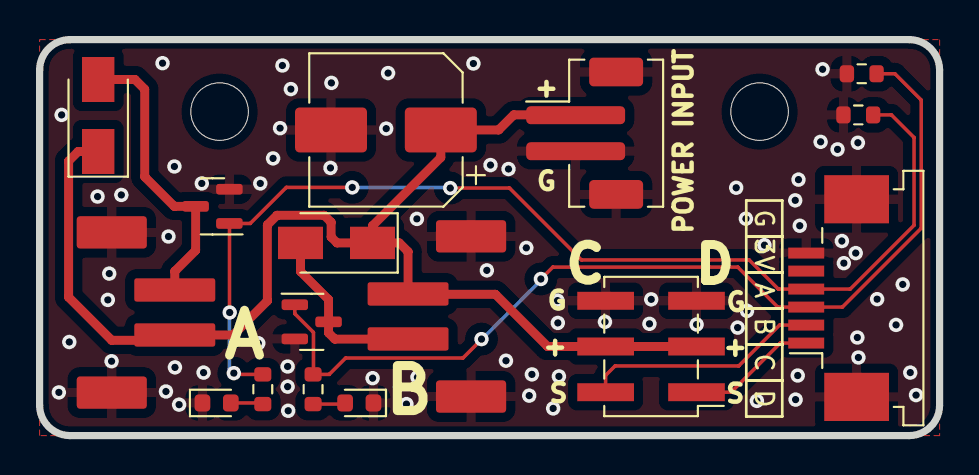
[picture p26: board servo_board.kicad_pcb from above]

Board: 2 copper layers, 50.0 x 22.0 mm, 18 parts (0 on the bottom side), 10 nets.

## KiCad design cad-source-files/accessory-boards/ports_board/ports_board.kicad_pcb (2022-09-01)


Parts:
H1, H2: MountingHole; MountingHole_3.2mm_M3_ISO14580
J2, J5, J7, J8: Conn_01x03; JST_PH_B3B-PH-SM4-TB_1x03-1MP_P2.00mm_Vertical
J9: Conn_01x06_MountingPin; TE_84952-6_1x06-1MP_P1.0mm_Horizontal

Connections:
+3V3: J2.2, J5.2, J7.2, J8.2, J9.5
/A: J2.1, J9.1
/B: J5.1, J9.2
/C: J7.1, J9.3
/D: J8.1, J9.4
GND: J2.3, J2.MP (MountPin), J5.3, J5.MP (MountPin), J7.3, J7.MP (MountPin), J8.3, J8.MP (MountPin), J9.6, J9.MP (MountPin)

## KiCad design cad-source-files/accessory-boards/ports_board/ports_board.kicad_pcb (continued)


Board: 2 copper layers, 50.0 x 22.0 mm, 7 parts (0 on the bottom side), 6 nets.

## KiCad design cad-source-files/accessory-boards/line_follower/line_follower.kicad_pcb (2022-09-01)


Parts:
H1, H2: MountingHole; MountingHole_3.2mm_M3_ISO14580
J9: Conn_01x06_MountingPin; TE_84952-6_1x06-1MP_P1.0mm_Horizontal
R3, R6, R9, R12: R100; R_0603_1608Metric
R5, R8, R10, R13: 10K; R_0603_1608Metric
U1, U2, U3, U4: QRE1113GR; OnSemi_CASE100CY

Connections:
+3V3: J9.5, R3.1, R5.1, R6.1, R8.1, R9.1, R10.1, R12.1, R13.1
/Button A: J9.4, R13.2, U4.3
/Button B: J9.3, R10.2, U3.3
/Button C: J9.2, R5.2, U1.3
/Button D: J9.1, R8.2, U2.3
GND: J9.6, J9.MP (MountPin), U1.2 (K), U1.4, U2.2 (K), U2.4, U3.2 (K), U3.4, U4.2 (K), U4.4
unnamed: R3.2, U1.1 (A)
unnamed: R6.2, U2.1 (A)
unnamed: R9.2, U3.1 (A)
unnamed: R12.2, U4.1 (A)


Board: 2 copper layers, 50.0 x 22.0 mm, 15 parts (0 on the bottom side), 10 nets.

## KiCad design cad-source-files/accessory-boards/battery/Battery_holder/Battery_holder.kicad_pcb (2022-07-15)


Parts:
BT1: Battery_Cell; 18650_holder
C1, C3: 220uF; CP_Elec_10x10.5
C2, C4: 4.7uF 100V; C_0805_2012Metric
D1: SX35_SCHOTTKY; D_SMA
J1, J2: Conn_01x04; JST_PH_S4B-PH-SM4-TB_1x04-1MP_P2.00mm_Horizontal
L1: L_Small; INDUCTOR_4.7uH_SMALL
R1, R2, R3: R_Small; R_0603_1608Metric
U1: SD6271; SOT-23-6

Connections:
+BATT: BT1.1 (+), C1.1, C2.1, L1.1, U1.4 (EN), U1.5 (VCC)
/CAN_H: J1.1, J2.1
/CAN_L: J1.2, J2.2
GND: BT1.2 (-), C1.2, C2.2, C3.2, C4.2, J1.4, J1.MP (MountPin), J2.4, J2.MP (MountPin), R1.2, R3.1, U1.2 (GND)
unnamed: D1.2 (A), L1.2, U1.1 (LX)
unnamed: R2.1, R3.2, U1.3 (FB)
unnamed: R1.1, U1.6 (OC)
VBUS: C3.1, C4.1, D1.1 (K), J1.3, J2.3, R2.2


Board: 2 copper layers, 13 parts (0 on the bottom side), 8 nets.

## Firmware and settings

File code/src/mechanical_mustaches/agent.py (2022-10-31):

import uasyncio as asyncio
from collections import OrderedDict
import gc

from mechanical_mustaches.auto import Auto
import mechanical_mustaches.motor
from mechanical_mustaches.stache_station import FakeStation



class Agent:
    """
    Agent's Manifesto
    1) An agent is in charge of their own destiny
    2) An Agent does not touch another Agent's variables (it is considered rude!)
    3) ALL agents must report to M, pronto!
    """

    def __init__(self, name, **nomnom):
        self.name = name
        m.add_agent(name, self)  # add self to m's dictionary
        self.state = None

    def __str__(self):
        return f"nice to meet you comrade I am {self.name}, I am a {self.__class__.__name__}"

    # ------------------------------------------------------------------------

    def check(self):
        pass
    
    def disabledPeriodic(self):
        pass

    # ------------------------------------------------------------------------

    def disabledInit(self):
        pass

    def teleopInit(self):
        pass

    def autonomousInit(self):
        pass

    def testInit(self):
        pass

    # ------------------------------------------------------------------------

    def report(self):
        return self.state

    def __call__(self, *args, **kwargs):
        if args and kwargs:
            return f"hurray for both!! args:{args}, kwargs{kwargs}"
        elif args:
            return f"you want an argument? {args}"
        elif kwargs:
            return f"I love kwargs <3, thank you for the {kwargs}"
        else:
            return f"ring ring hello this is {self.name}, who's there"

    def __repr__(self):
        return f'OG_{self.name}'

    # ------------------------------------------------------------------------


class CEO:
    def __init__(self, name):
        self.name = name
        self.agents = OrderedDict()
        self.state = 'disabled'  # auto, test, disabled
        self.autos = []
        self.the_report = []
        self.ss = FakeStation  # create fake until real is injected

    def talk(self):
        print(f'hello i am {self.name.upper()} nice to meet you {self.agents}')

    def add_agent(self, name: str, agent: Agent):
        self.agents.update({name: {'self': agent, 'outputs': {}}})

    def find_outputs(self):
        outputs = (mechanical_mustaches.motor.Motor)
        for name, agent in self.agents.items():
            this_agent = agent["self"]
            for this_name, value in this_agent.__dict__.items():  # (name, value) = (k, v) --> (key, value)
                # print(this_name, value)
                if isinstance(value, outputs):
                    # print(f"found name:{this_name} and value:{value}")
                    self.agents[this_agent.name]['outputs'][this_name] = value

    def make_report(self):
        for name, agent in self.agents.items():
            self.the_report.append([f'{name}_state', agent['self']])
            for o_name, output in agent['outputs'].items():
                self.the_report.append([f'{name}_{o_name}_state', output])

    def report(self):
        return {k: v.report() for k, v in self.the_report}

    def set_LCD(self, lcd):
        self.lcd = lcd

    def post(self, the_post: str):
        self.lcd.print(the_post)
        print(the_post)

    # ------------------------------------------------------------------------

    async def check(self):  # This is the teleopPeriodic function
        for agent in self.agents.values():
            agent['self'].check()
            await asyncio.sleep_ms(0)

    async def disabledPeriodic(self):
        for agent in self.agents.values():
            agent['self'].disabledPeriodic()
            await asyncio.sleep_ms(0)

    # ------------------------------------------------------------------------

    def testInit(self):
        print('TESTINGGGGG', self.agents.values())
        for agent in self.agents.values():
            agent['self'].testInit()
            
    def disabledInit(self):
        for agent in self.agents.values():
            agent['self'].testInit()
            
            
    def teleopInit(self):
        for agent in self.agents.values():
            agent['self'].testInit()

    # ------------------------------------------------------------------------

    async def auto_check(self):
        for auto in self.autos:
            auto.check()
        await asyncio.sleep_ms(0)

    def add_auto(self, playbook: list, **kwargs):
        archie = Auto(**kwargs)
        self.autos.append(archie)
        archie.run(playbook, start=False)

    def run_auto(self, book):
        book.append(lambda: self.change_state('disabled'))
        self.change_state('auto', book)

    def retire(self, target):
        print(f"I'm sorry {target} it is time to die!")
        for auto in self.autos:
            if auto.name == target:
                auto.retired = True

    # ------------------------------------------------------------------------

    async def loop(self):
        while True:
            if self.state == 'teleop':  # auto, test, disabled
                await self.robot.teleopPeriodic()
                await self.robot.robotPeriodic()
            elif self.state == 'auto':
                await self.robot.autonomousPeriodic()
                await self.robot.robotPeriodic()
            elif self.state == 'test':
                await self.robot.testPeriodic()
                await self.robot.robotPeriodic()
            elif self.state == 'disabled':
                await self.robot.disabledPeriodic()
                await self.robot.robotPeriodic()
            self.ss.check()
            gc.collect()
            await asyncio.sleep_ms(20)

    # ------------------------------------------------------------------------

    def change_state(self, state, *auto_book):
        print(f'changing state to {state}')
        if state == 'disabled':
            self.robot.disabledInit()
            self.disabledInit()
        elif state == 'auto':
            self.autos.clear()
            if not auto_book:
                self.robot.autonomousInit()
            else:
                self.add_auto(auto_book[0])
        elif state == 'test':
            self.robot.testInit()
            self.testInit()
        elif state == 'teleop':
            self.robot.teleopInit()
            self.teleopInit()

        self.state = state

    # ------------------------------------------------------------------------

    def run(self, robot):
        self.robot = robot
        self.robot.robotInit()
        self.robot.disabledInit()
        self.find_outputs()
        self.make_report()
        self.post('BOOT COMPLETE')
        loop = asyncio.get_event_loop()
        loop.create_task(self.loop())
        loop.run_forever()

    # ------------------------------------------------------------------------


m = CEO('m')

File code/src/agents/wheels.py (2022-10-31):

import mechanical_mustaches as mm



class Wheels(mm.Agent):
    def __init__(self, name: str, louie: dict , roger: dict):
        super().__init__(name)
        self.name = name
        self.louie = mm.Motor(**louie)
        self.roger = mm.Motor(**roger)
        self.state = 'sleeping'
        print("{} has rolledddddddd on in".format(self.name))
        # self.driver = driver

    def tankdrive(self, left, right):
        
        self.louie.set(left)
        self.roger.set(right)
        
    def stop(self):
        
        self.louie.set(0)
        self.roger.set(0)
        
#     def check(self):
#         self.tankdrive(self.driver.get_axis('LY'), self.driver.get_axis('RY'))
    
    
    def drive(self, speed: float, turn: float):
        """speed and turn take arguments from -1 to 1"""
        
        wheels = [speed + turn, speed - turn]
        
        for wheel in wheels:
            if wheel > 1:
                wheel = 1
            if wheel < -1:
                wheel = -1
        # print(wheels)
        self.louie.set(wheels[0])
        self.roger.set(wheels[1])
        
            
        
        

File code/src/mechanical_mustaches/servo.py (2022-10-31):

from machine import Pin, PWM
import utime



class Servo:
    # range is 70 --> 650
    def __init__(self, pin: int, *, freq:int=650, min:int= 200, max:int= 1000, name='servo'):
        self.name = name
        self.pin = PWM(Pin(pin), freq=freq, duty=0)
        utime.sleep_ms(10)
        self.pin.init(freq=650, duty=0)
        self.min = min
        self.max = max
        
        utime.sleep_ms(10)
        self.pin.duty(0)
        
        
    def raw(self, duty):
        self.pin.duty(duty)
        
    def set(self, pos):
        """ we want range from -1 to 1 """ 
        duty = self.clamp(pos, -1, 1)
        self.pin.duty(duty)
    
    def degrees(self, deg):
        """ input deg from 0 to 180 """
        duty = self.clamp(deg , 0, 180)
        self.pin.duty(duty)
    
    def clamp(self, val, _min, _max):
        return int(((val - _min) / (_max - _min)) * (self.max - self.min) + self.min)
    
    def report(self):
        return self.pin.duty()

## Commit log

2022-07-13 mini mustache flutters in :D
    [Big Kahuna Board-B_Cu.gbr, Big Kahuna Board-B_Mask.gbr, Big Kahuna Board-B_Paste.gbr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]
2022-07-15 micro_yehansa tells stories :)
    [Battery_holder.kicad_pcb, Battery_holder.kicad_sch]
2022-07-24 carl the controller and mo play sockets :D
2022-08-07 move Olivia's stuffy stuff to the correct repo
    [robo_car.kicad_pcb, robo_car.kicad_sch]
2022-08-07 add logo
    [robo_car.kicad_pcb]
2022-08-22 Still gotta fix the Angie zong shtuff but thats mostly it
    [robo_car.kicad_pcb, robo_car.kicad_sch]
2022-08-27 squiggly squiggly
    [robo_car.kicad_pcb]
2022-08-31 assembly exports
    [line_follower.kicad_pcb, ports_board.kicad_pcb, servo_board.kicad_pcb]
2022-08-31 why uhappy git ;'(
    [servo_board.kicad_pcb]
2022-09-01 Mo has pico minions :)
2022-09-08 3rd try lets go
    [robo_car.kicad_pcb, robo_car.kicad_sch]
2022-09-08 Revert "3rd try lets go"
    This reverts commit 3f093a060dbc0dc4159fd1f3f57facfb81c75c62.
    [robo_car.kicad_sch]
2022-09-10 jerry joypad jumps in
    [joypad.kicad_pcb, joypad.kicad_sch]
2022-09-10 finally finally the last one oh my god ive switched these pins a dozen times
    [robo_car.kicad_sch]
2022-09-10 ok NOW its done
    [robo_car.kicad_pcb, robo_car.kicad_sch]
2022-09-12 Revert "Webster has a lot of mean butts :)"
    This reverts commit 07df7bce965628eeab175f7801f36550b728a9df.
    [agent.py, neo.py, wheels.py]
2022-09-26 Mo gets his Stache'Board dashboard and mo'
    mo gets his stache'board, repl, m does rez on shache'board, mo can make pictures and push css and webpage gets button maker helper also a bit of housekeeping
2022-09-27 things are connected but theres still more things to be done
    [joypad.kicad_pcb, joypad.kicad_sch]
2022-09-27 ground pads were weird. All fixed :)
    [joypad.kicad_pcb]
2022-09-28 drawings and viass wooooooo
    [joypad.kicad_pcb]
2022-09-28 nvm i wanted text in a different place
    [joypad.kicad_pcb]
2022-09-28 okok thisss time cause now it has a mustachey logo
    [joypad.kicad_pcb]
2022-10-05 mo diggity (•┏෴┓•)
    timmy waits
    archie loops
    stache station exists
    heartbeat beats
    func button interrupts
    status neo tells shows boot state
    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
2022-10-08 Mo becomes very hard to kill
    with only his pinky finger he will serve that webpage
2022-10-09 dr. mo will LCD you now (O╭_ ╮O ´)
2022-10-17 agents reporting for dootie :)
    wally clamps
    rez -> report
    mmmmm boot message
2022-10-18 mo remembers his repls (´┏o┓｀)
2022-11-19 gettin down with the qwiic-ness
    [i2c_board.kicad_pcb, i2c_board.kicad_sch, robo_car.kicad_pcb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]
2022-11-19 mo can see us now 👀
    [mo-stache.kicad_pcb]
2022-11-20 qwiic quick board
    [i2c_board.kicad_pcb, i2c_board.kicad_sch]
2022-11-21 mo 4 has spawned
    [i2c_board.kicad_pcb, robo_car.kicad_pcb, robo_car.kicad_sch]
2022-12-03 12-2 boards ordered
    [i2c_board.kicad_pcb, joypad.kicad_pcb, joypad.kicad_sch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]
